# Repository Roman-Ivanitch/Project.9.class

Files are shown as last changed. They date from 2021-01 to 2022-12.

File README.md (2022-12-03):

# Project.9.class 
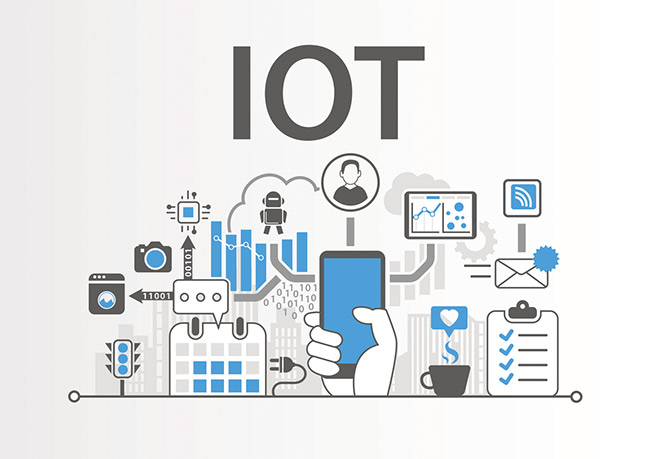
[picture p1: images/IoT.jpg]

___
## Проект 9 класс Рабочая лампа.
## Проект 10 класс Умная лампа V2.
Красикова Романа RassirHakerCorporation@mail.ru 
+ [Страница проекта эектронной начинки в EasyEDA](https://easyeda.com/RassirHaker/10-class)
+ [Сборка лампы](https://github.com/Roman-Ivanitch/Project.9.class/blob/main/dimensional_drawing/README.md)
+ [Настройки в прошивке](https://github.com/Roman-Ivanitch/Project.9.class/tree/main/program_code#readme) 
+ [Руководство по настройке](https://github.com/Roman-Ivanitch/Project.9.class/blob/main/user_manual.md)
+ [Источники информации](https://github.com/Roman-Ivanitch/Project.9.class/blob/main/sources_of_information/README.md)
+ [Исходники кода](https://github.com/Roman-Ivanitch/Project.9.class/blob/main/source_codes/README.md)
## :bulb: Что это такое
Лампа, крепящаяся на стенку над столом. На лампе 2 ряда светодиодной 12-24 вт. Ленты и ряд адресной светодиодной ленты (60 LED/м) отрезками 730 мм. 
Управляется через телефон приложением Blynk (не новым Blynk IoT). Лента уложена в продольные канавки (пазы), 
тем самым не ослепляет и освещает нужную рабочую зону. Изготовлена из "Планкена" 90мм. Питается от внешнего блока питания 12в 3а.

В папке elecktronika находиться гербер файл для заказа плат (я заказывал на [JLCPCB](https://jlcpcb.com/)). 
На плате находиться модуль(микроконтроллер) ESP12f(даташит в папке материалы, источники),
2 mosfet ключа, реле 5V, понижающий регулируемый(калибровочный)) DC-DC преобразователь, стабилизаторы напряжения  3,3 и 12 вольт.

Плату можно питать в диапазоне 10-18 вольт. на плате лишний стабилизатор напряжения на 12 вольт, если его убрать то рекомендую питать от БП 12В, если оставить, то от 14 вольт, но лучше наверно будет поставить вместо стабилизатора стабилитрон. в течении последующего года это страница будет обновляться, скорее всего разведу новую более совершенную универсальную плату. Актуальную плату лучше смотреть на [EasyEDA](https://easyeda.com/RassirHaker/10-class). 

Более подробное описание: 
+ [Проект_9_класс.docx](https://github.com/Roman-Ivanitch/Project.9.class/blob/main/%D0%9F%D1%80%D0%BE%D0%B5%D0%BA%D1%82_9_%D0%BA%D0%BB%D0%B0%D1%81%D1%81.docx) проект на олимпиаду по технологии 9 класс
+ [Проект_10_класс.docx](https://github.com/Roman-Ivanitch/Project.9.class/blob/main/%D0%9F%D1%80%D0%BE%D0%B5%D0%BA%D1%82_10_%D0%BA%D0%BB%D0%B0%D1%81%D1%81.docx) проект на олимпиаду по технологии 10 класс
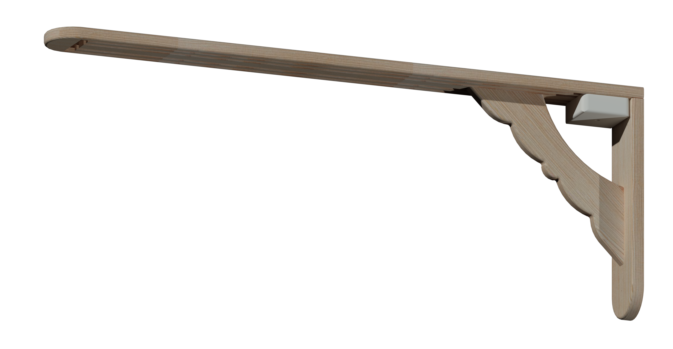
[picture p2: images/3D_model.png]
3d

## QR-code страницы проекта на github 
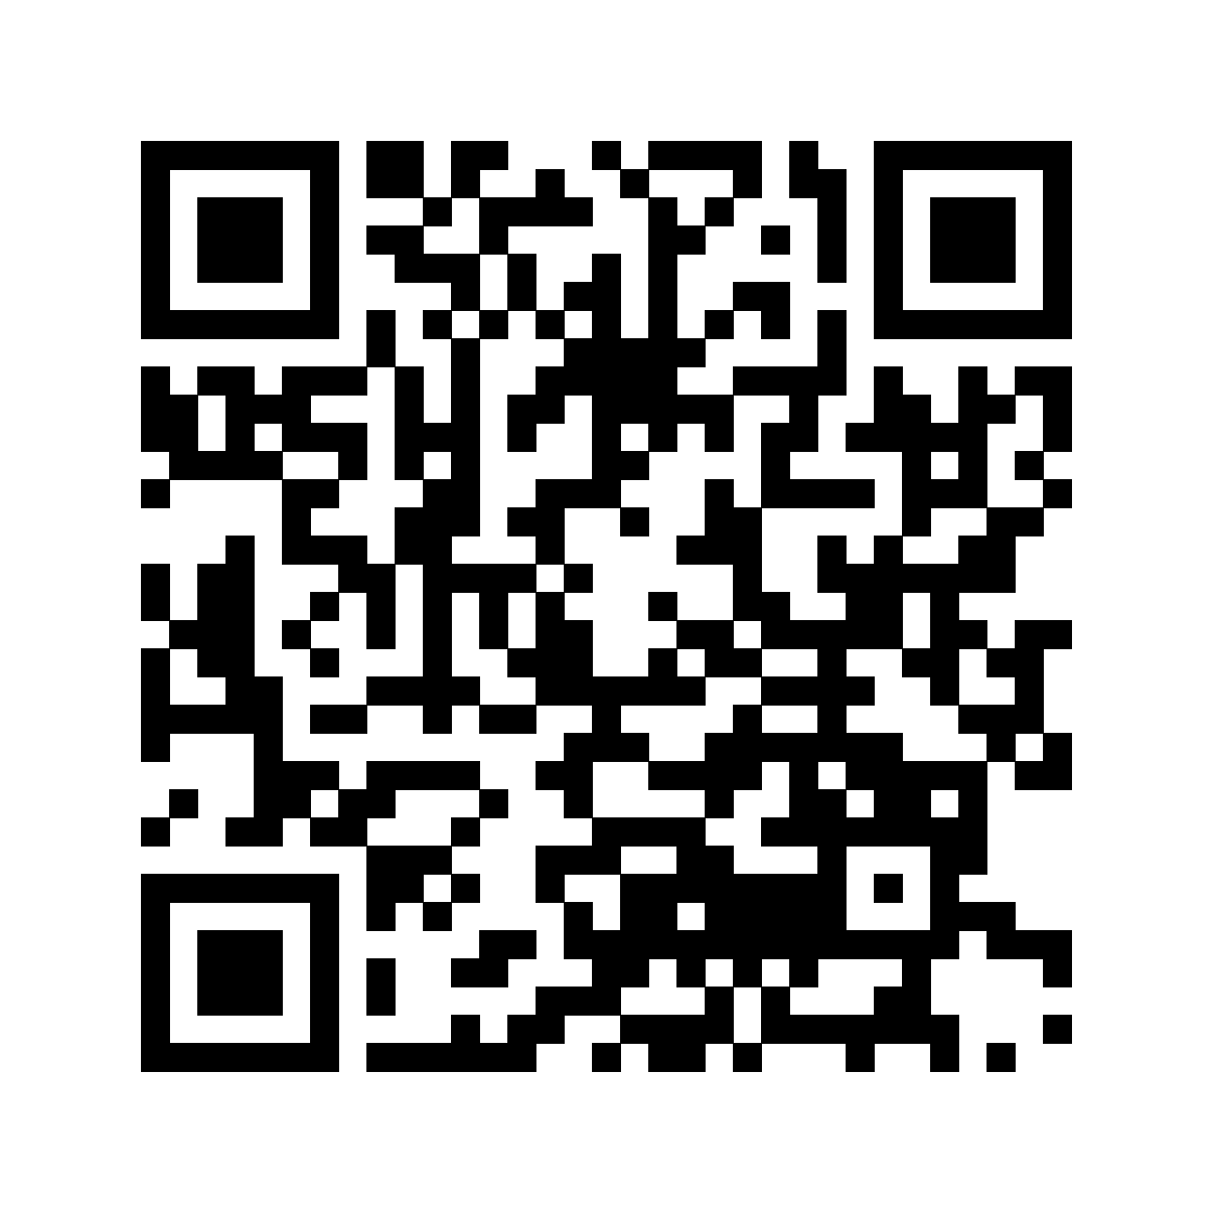
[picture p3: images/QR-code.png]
Qr-code

___

Репозиторий не переименован, потому что на печатных пплатах я указал эту ссылку. Если переименую ссылка по url будет не доступна, а платы уже изготовлены. 

Первый опыт работы в гите...

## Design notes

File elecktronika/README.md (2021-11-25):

# БОЛЕЕ АКТУАЛЬНАЯ ВЕРСИЯ НА [EasyEDA](https://easyeda.com/RassirHaker/10-class)
+ BOM_Smart Lamp V2_2021-09-25.csv - таблица используемых компонентов
+ Gerber_PCB_10 class_1.zip - гербер файл платы электроники
+ Gerber_END_2021-09-25.zip - гербер файл платы соединений ленты (для удобства, внешней информации и красоты)
+ Schematic_10 class_2021-09-17.png - схема, актуальную смотри на [EasyEDA](https://easyeda.com/RassirHaker/10-class)

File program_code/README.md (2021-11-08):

# Program code 
Код писал в Arduino EDA, как настраивать читайте [тут](https://alexgyver.ru/arduino-first/)

Мои ссылки менеджера библиотек:
> https://dl.espressif.com/dl/package_esp32_index.json

> http://arduino.esp8266.com/stable/package_esp8266com_index.json

Код в папке start потому, что первый файл кода назван start, особенность Arduino EDA.

## Settings 
___
Для работы с блинком надо свой токен, но так как у лампы есть тумблер переключения сети, что бы можно задать несколько серверов и wifi сети, то для каждого сервера и wifi сети надо задать свои настройки. 

Если мы используем несколько серверов то для каждого сервера надо указать свой токен
```C++
char auth[] = "токен";          // лампа Blynk-cloud.com // Токен приложения Blynk
char auth_server[] = "токен";   // лампа local-server    // Токен приложения Blynk
```
Так же если используем свой сервер, то надо и задать его ip адрес, в моём случае, для доступа из сети интернет я подключил статический ip адрес (для оф.сервера задавать ip не нужно)
```C++
char ip_local[] = "ip адрес";             // свой server - local ip   // к примеру 192.168.88.200
char ip_net[] = "ip адрес";               // свой server - internet ip
```
Так же в коде надо задать параметры wifi сети, пароль и ssid
```C++
char ssid_home[] = "wi-fi-home-0000575";  // сеть wi-fi
char pass_home[] = "7851xdwifi";          // Пароль WiFi

char ssid_phone[] = "A30";                // Мобильная точка доступа WiFi
char pass_phone[] = "87651234";           // Пароль WiFi

```
Пины подключения ленты/тумблера/обвязки (пины подключены как на печатной плате)
```C++
#define LED_DT  4               // Пин, куда подключен DIN ленты
#define LED     14              // Пин подключения лампы
#define LED1    12              // Пин подключения реле 

#define NET1 5                  // пин подключения кнопки выбора сети 1              
#define NET2 13                 // пин подключения кнопки выбора сети 2
```
Так же надо указать число светодиодов в подключеной адресной ленте
```C++
#define LED_COUNT 50            // Число светодиодов в кольце/ленте
```
### Вот собственно все настройки! 
___
Единственное правда можно поиграть с назначениями положения тумблера
```C++
  // Запуск Blynk (подключение,токен,WiFi,пароль) в зависимости от кнопки // выбор сети

  if (digitalRead(NET1) == 1) Blynk.begin(auth, ssid_phone, pass_phone); 
  // мобил точка доступа и Blynk-cloud.com

  else if (digitalRead(NET2) == 1) Blynk.begin(auth_server, ssid_phone, pass_phone, ip_net, 8080);
  // мобил точка доступа и свой сервер через интернет

  else Blynk.begin(auth_server, ssid_home, pass_home, ip_local, 8080);
  // точка доступа wifi  и свой локальный сервер

```
## tabs 
___
+ start.ino - настройки, функции setup и loop
+ blynk.ino - назначение виртуальных пинов приложения блинк
+ function.ino - функции обработки и воспроизведения режимов, писал не я, брал у [AlexGyver](https://alexgyver.ru/ws2812b-fx/)
+ leds.ino - эффекты для адресной ленты

## libraries
___
+ [FastLED](https://github.com/FastLED/FastLED) 
+ [blynk](https://github.com/blynkkk/blynk-library/releases/tag/v0.5.1), документацию читайте [тут](http://docs.blynk.cc/)

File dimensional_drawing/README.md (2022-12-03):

# Конструкция и сборка лампы
lamp
## Детали
---
Для лампы есть чертежи, 3D модели и эскизы. 
Также есть технологические карты в [проексте](https://github.com/Roman-Ivanitch/Project.9.class/blob/main/%D0%9F%D1%80%D0%BE%D0%B5%D0%BA%D1%82_10_%D0%BA%D0%BB%D0%B0%D1%81%D1%81.docx), не блещут качеством, но всёже есть.

в папках:

+ [basis](https://github.com/Roman-Ivanitch/Project.9.class/tree/main/dimensional_drawing/basis) - основание лампы

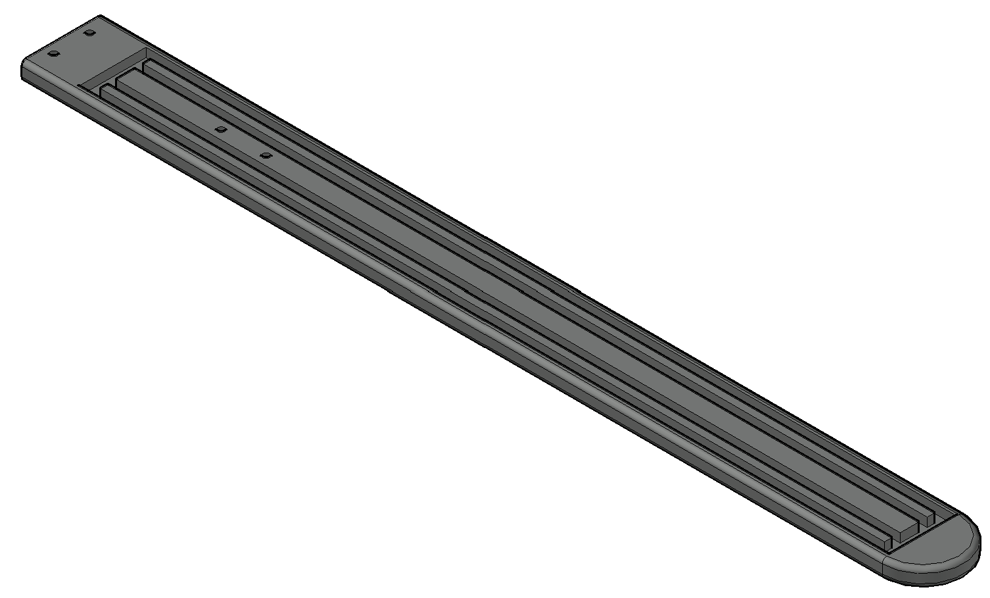
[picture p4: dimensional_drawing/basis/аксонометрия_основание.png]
basis


+ [support](https://github.com/Roman-Ivanitch/Project.9.class/tree/main/dimensional_drawing/support) - опора лампы

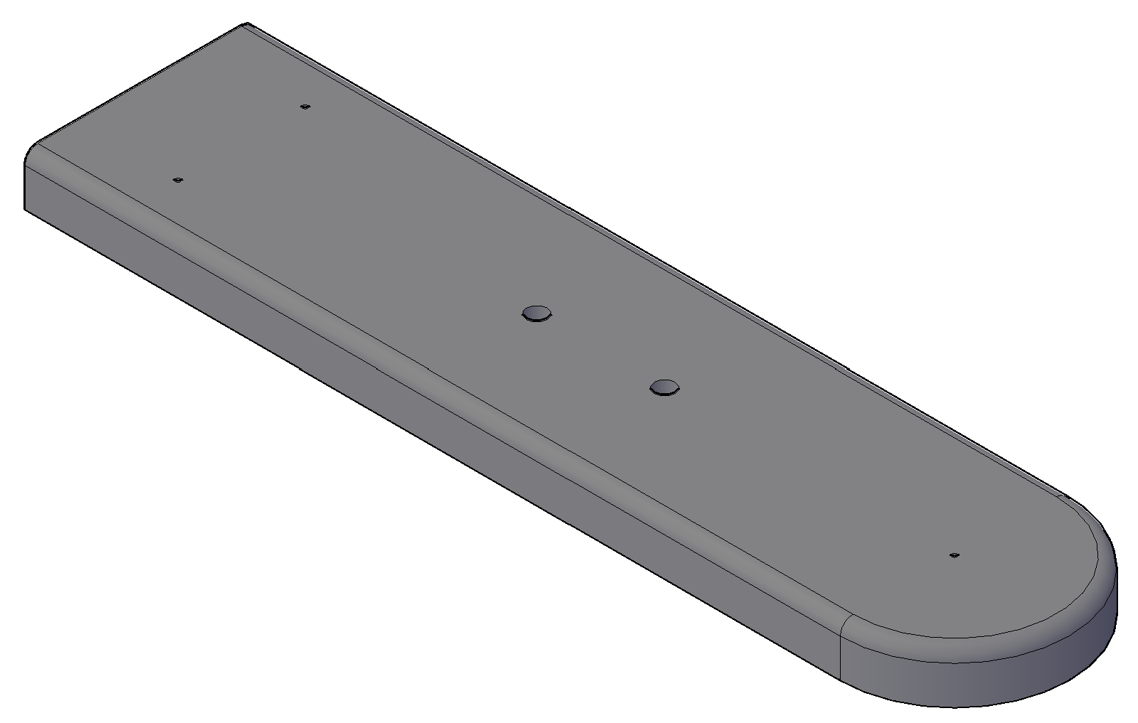
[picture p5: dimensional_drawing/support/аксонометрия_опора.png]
support


+ [gusset](https://github.com/Roman-Ivanitch/Project.9.class/tree/main/dimensional_drawing/gusset) - косынка лампы, с чертежом туго/некачественно, но всёже есть

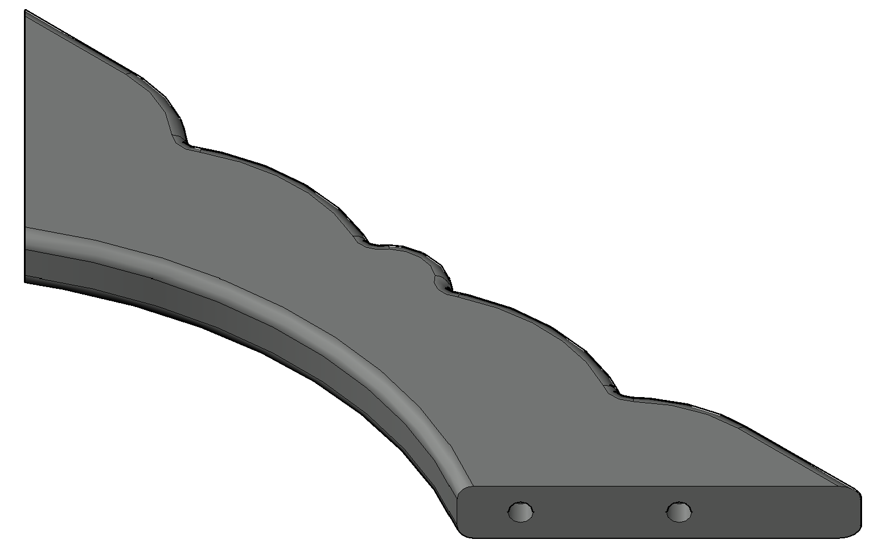
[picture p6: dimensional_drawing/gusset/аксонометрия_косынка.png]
gusset


+ [junction_box](https://github.com/Roman-Ivanitch/Project.9.class/tree/main/dimensional_drawing/junction_box) - 3D модель распред коробки, я использую купленную под цвет лампы, но как появится 3D принтер, распечатаю свою 

+ [lamp](https://github.com/Roman-Ivanitch/Project.9.class/tree/main/dimensional_drawing/lamp) - собранная лампа, со всеми видами

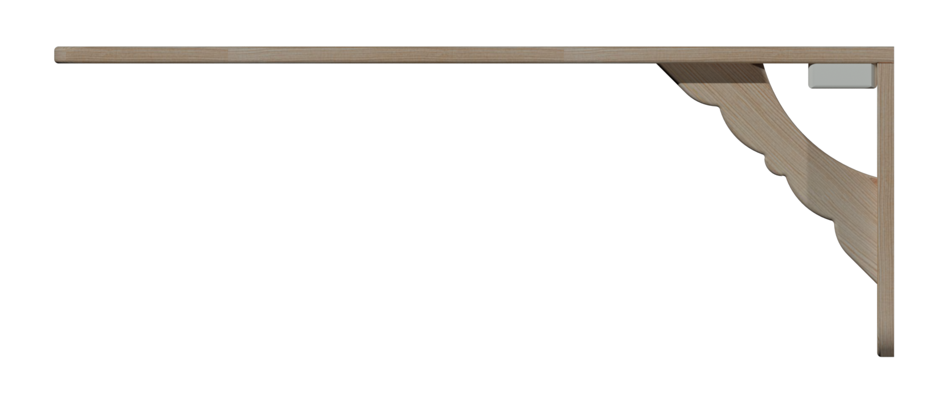
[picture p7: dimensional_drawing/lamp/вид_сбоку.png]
lamp


## Сборка
---

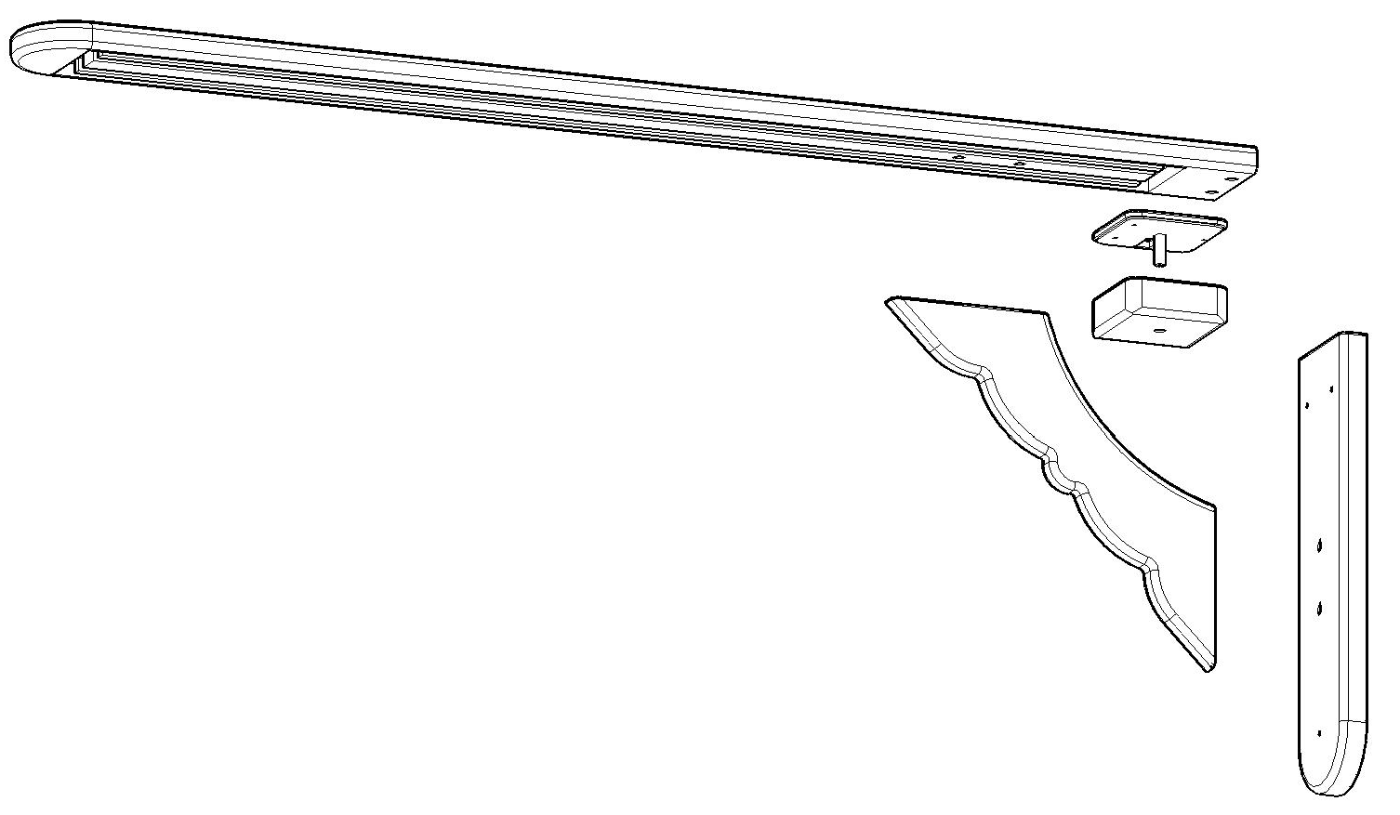
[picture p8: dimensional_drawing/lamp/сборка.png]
Сборка


Сборка лампы осуществляется на круглые вставные штифты 20 х Ø8 мм, распред коробка крепиться ко снованию на два саморезика и крепиться на стену при помощи шурупов 75 мм, которые закрываються мебельными заглушками.

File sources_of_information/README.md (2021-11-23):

# Источники 
## Ссылки 
+ Ютуб канал [AlexGyverShow](https://www.youtube.com/c/AlexGyverShow) много видео в адресной лентой( у него взяты идеи и исходники для первой лампы)
+ Ютуб канал [Инженерка](https://www.youtube.com/c/%D0%98%D0%BD%D0%B6%D0%B5%D0%BD%D0%B5%D1%80%D0%BA%D0%B0), все видео связаны с Blink
+ [Уроки на сайте Alexgyver](http://alexgyver.ru/arduino_lessons/)
+ [Как пользоваться github](https://www.youtube.com/watch?v=JfpCicDUMKc&t=1s) :smile: 
+ [Как развести печатную плату](https://www.youtube.com/watch?v=qXS617cC6Bw&t=0s)
+ [Как развести печатную плату в easyeda](https://youtu.be/9FS1m_K8aWI)
+ [Тоже инфа про платы](https://alexgyver.ru/lessons/naked-chip)
## Литература 
+ [Архетектура интернета вещей](https://github.com/Roman-Ivanitch/Project.9.class/blob/main/sources_of_information/%D0%90%D1%80%D1%85%D0%B8%D1%82%D0%B5%D0%BA%D1%82%D1%83%D1%80%D0%B0%20%D0%B8%D0%BD%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) - Перри Ли
+ [Интернет вещей Иследования и область применения](https://www.chitai-gorod.ru/catalog/book/892185/) - Е.П Зараменских И.Е Артемьев
+ [ARDUINO от азов програмирования до создания практических устройств](https://www.chitai-gorod.ru/catalog/book/1050770/) - Белов А.В
+ [Управление модулем ARDUINO по WiFi с мобильных устройств](https://www.chitai-gorod.ru/catalog/book/1224716/) - Белов А.В
+ [Учебное пособие Интернет вещей](https://github.com/Roman-Ivanitch/Project.9.class/blob/main/sources_of_information/%D1%83%D1%87%D0%B5%D0%B1%D0%BD%D0%B8%D0%BA%20%D0%98%D0%92%20%D0%A0%D0%BE%D1%81%D0%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) - (учебник ИВ Росляков)  А. В. Росляков, С. В. Ваняшин, А. Ю. Гребешков
+ [ESP8266_Pinout]https://github.com/Roman-Ivanitch/Project.9.class/blob/main/sources_of_information/ESP8266_Pinout_Diagrams.pdf) - распиновка модулей ESP8266
+ [Datasheet_ESP12f](https://github.com/Roman-Ivanitch/Project.9.class/blob/main/sources_of_information/ai-thinker_esp-12f.pdf) - даташит модуля ESP12f

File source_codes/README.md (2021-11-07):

# Исходники source_codes 
+ [Bridge Мост Blynk](https://www.youtube.com/watch?v=jMqfWySQdbk) - [download](https://yadi.sk/d/I97H1rZ83KzqM6)
+ [Переподключение Blynk](https://www.youtube.com/watch?v=k9q7FT3p9dM&t=964s) - [download](https://yadi.sk/d/FLdh-S9G3Yur3W)
+ [Голосовой асистент Яндекс Алиса управление Blynk](https://www.youtube.com/watch?v=9rQ1yl00WwE&t=1286s) - [download]( https://yadi.sk/d/YaQMMV3Cu8t1OA)
+ [Адресная лента WS2812_FX-master](https://www.youtube.com/watch?v=_h-Vj8Z6hqs&t=445s) - [download](http://alexgyver.ru/ws2812b-fx/), [download from github](https://github.com/AlexGyver/WS2812_FX)
+ [Модифицированная лампа Гайвера](https://www.youtube.com/watch?v=9o8aKMHTWc4&t=6s) - [download](https://yadi.sk/d/7gbUdzGVLFRcXw)

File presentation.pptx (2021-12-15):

## Умная лампа V2

Муниципальное казённое образовательное учреждение
«Средняя общеобразовательная школа п. Алексеевск»

Выполнил: Учащийся 10 класса
МКОУ СОШ п. Алексеевска
Красиков Роман.

п. Алексеевск, 2021г.

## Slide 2


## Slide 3

Разработка. Электроника.

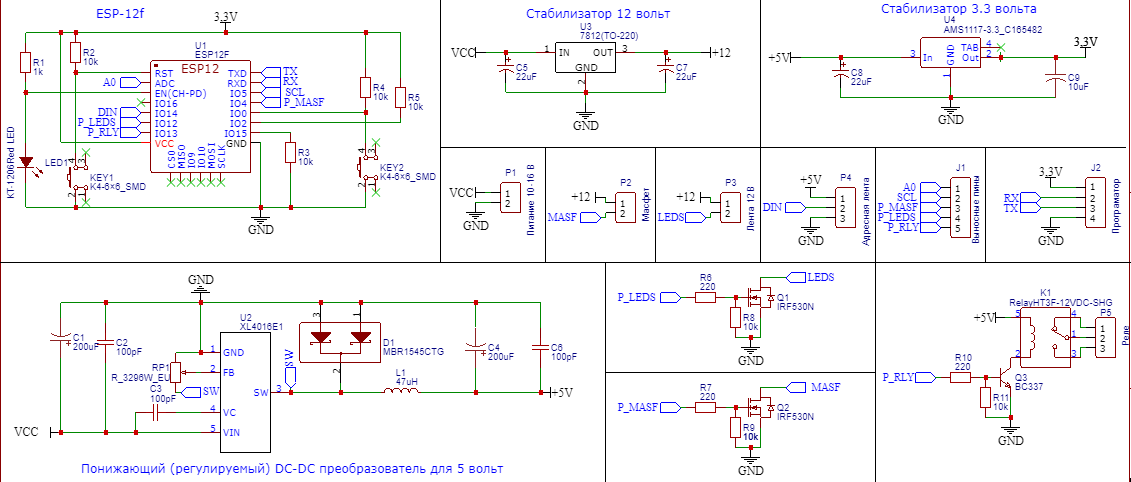
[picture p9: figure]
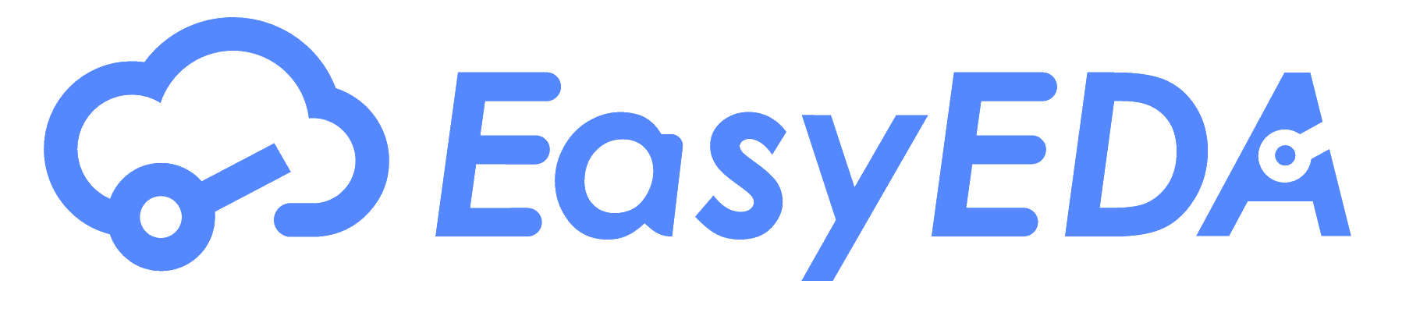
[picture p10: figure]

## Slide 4

Разработка. Дизайн.

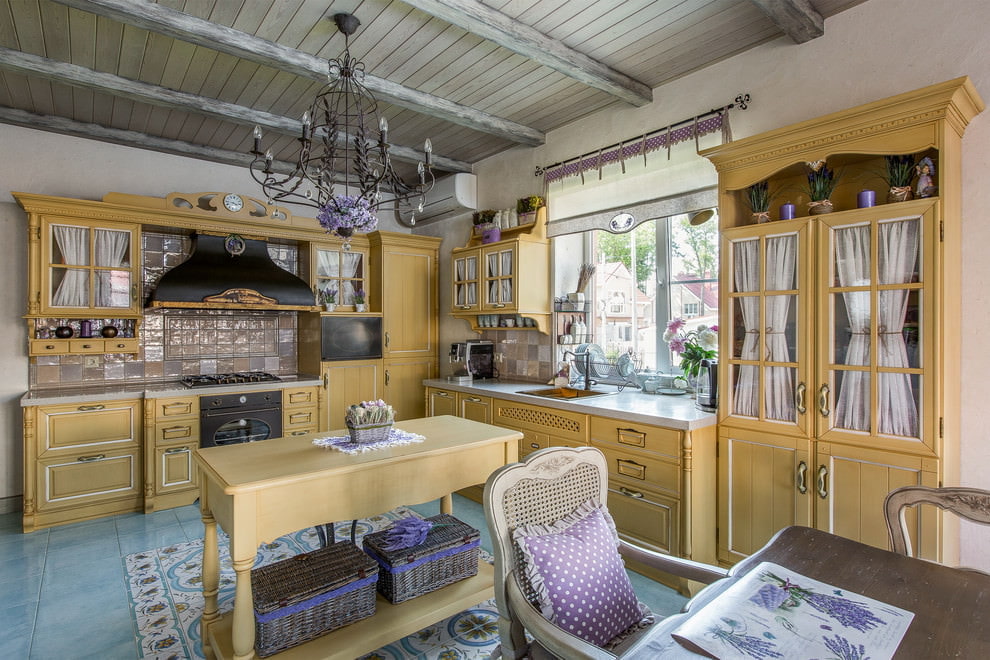
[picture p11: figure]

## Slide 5

Разработка. ПО.

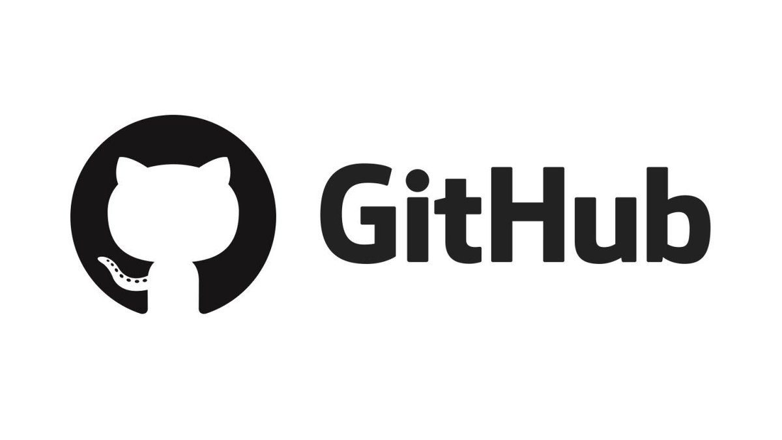
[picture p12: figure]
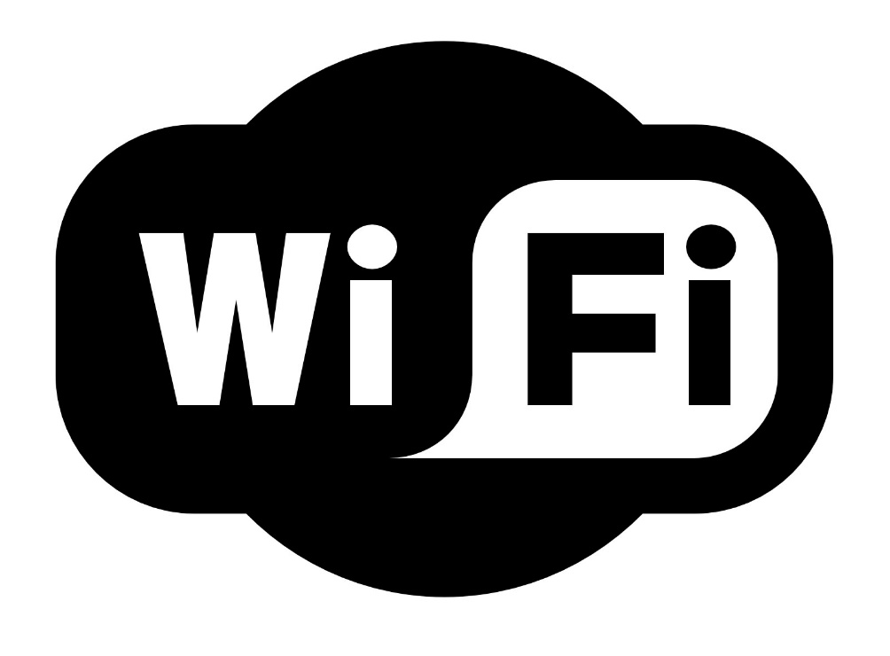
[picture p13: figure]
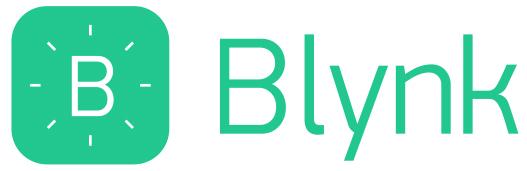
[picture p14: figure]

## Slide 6

Предварительное экономическое обоснование.

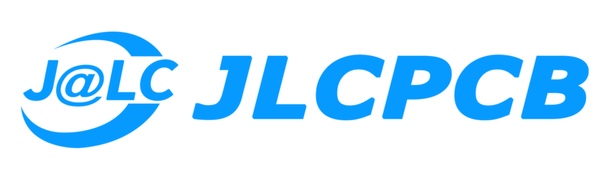
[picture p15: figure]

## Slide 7

Технологический этап. Детали.

опора
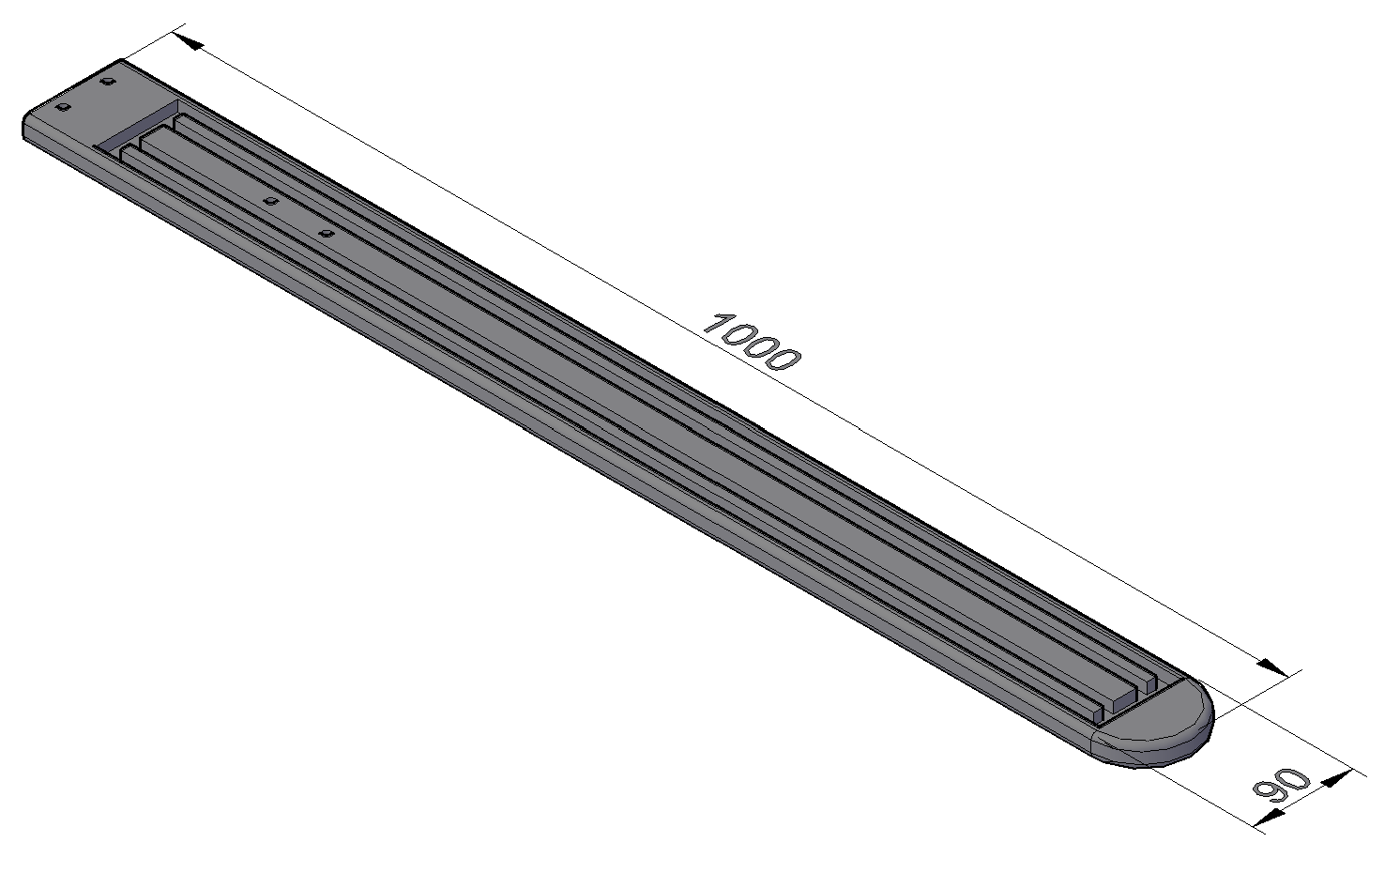
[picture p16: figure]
основание

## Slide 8

Чертежи.

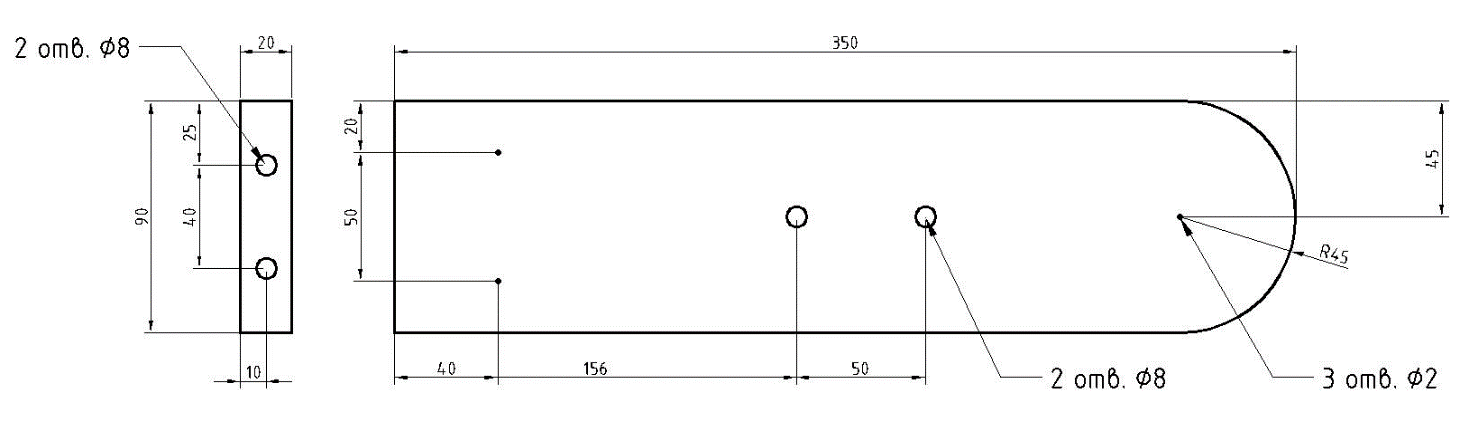
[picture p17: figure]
черчёж_опоры
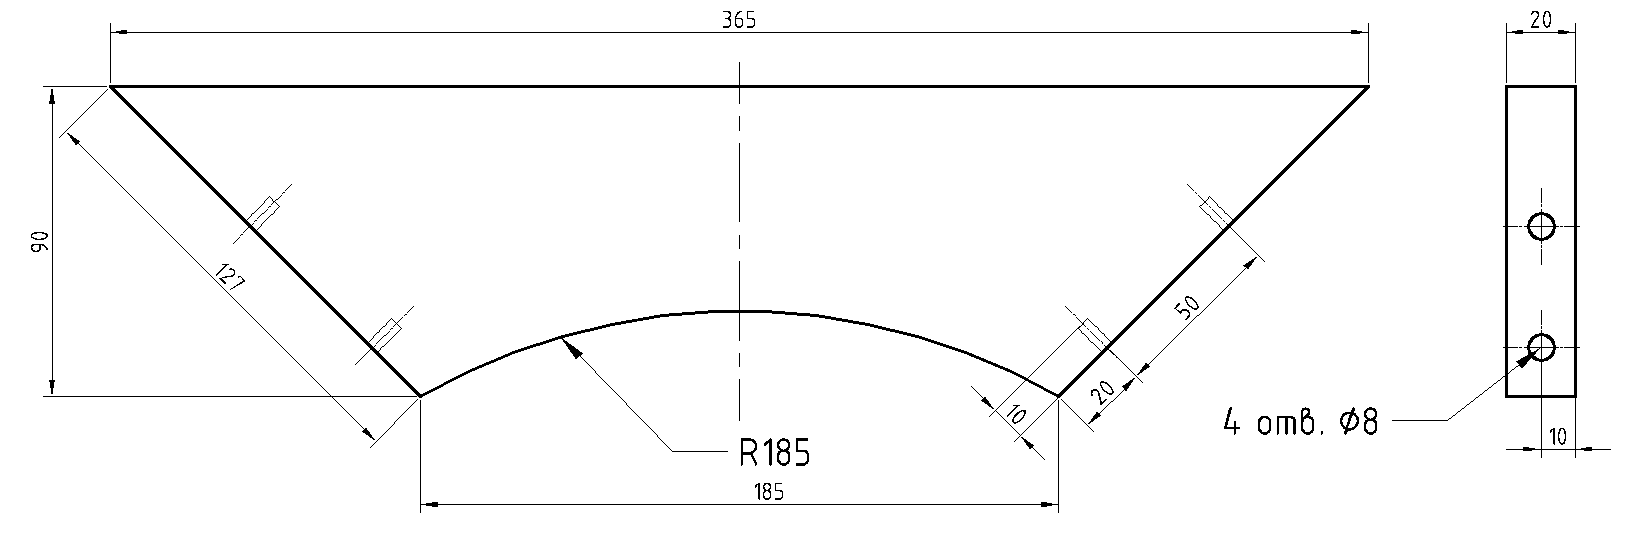
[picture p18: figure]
Черчеж_косынки
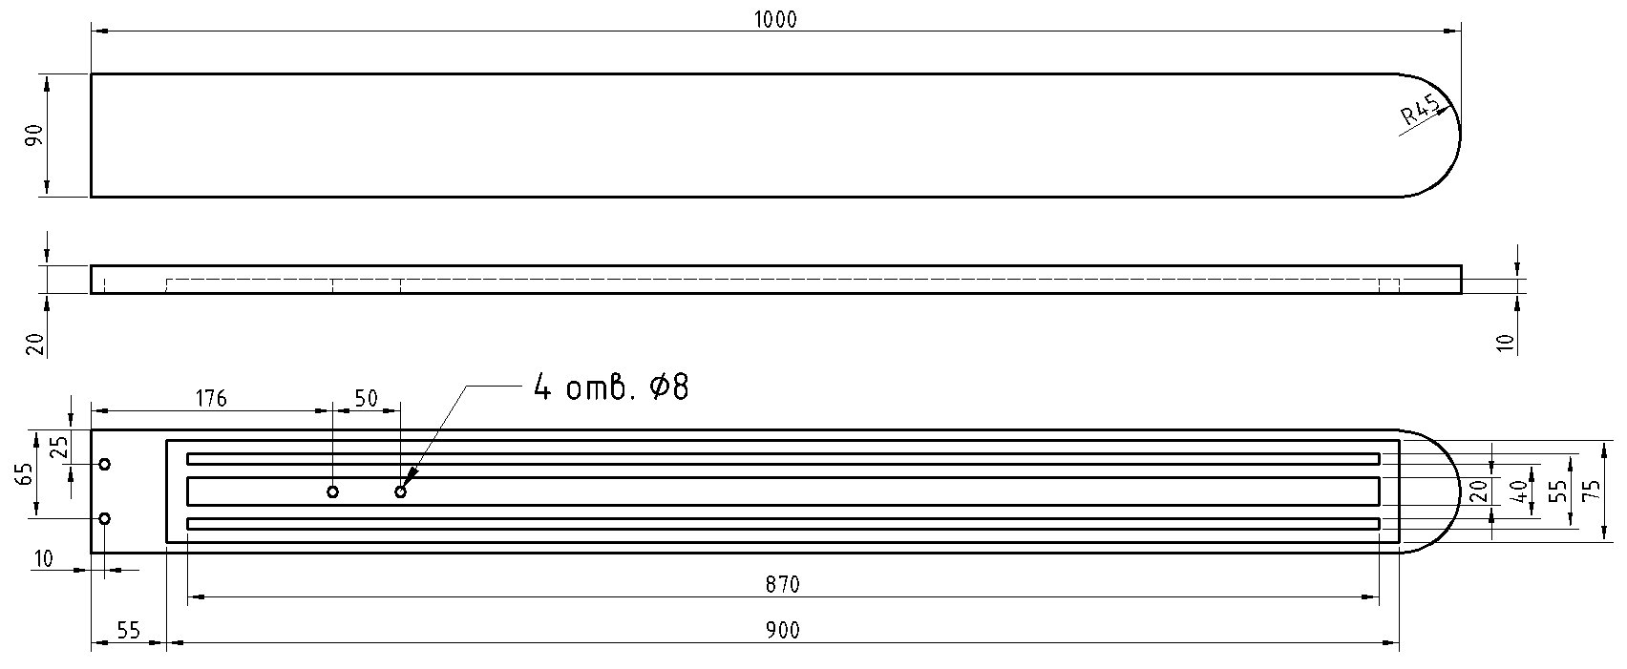
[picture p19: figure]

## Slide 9

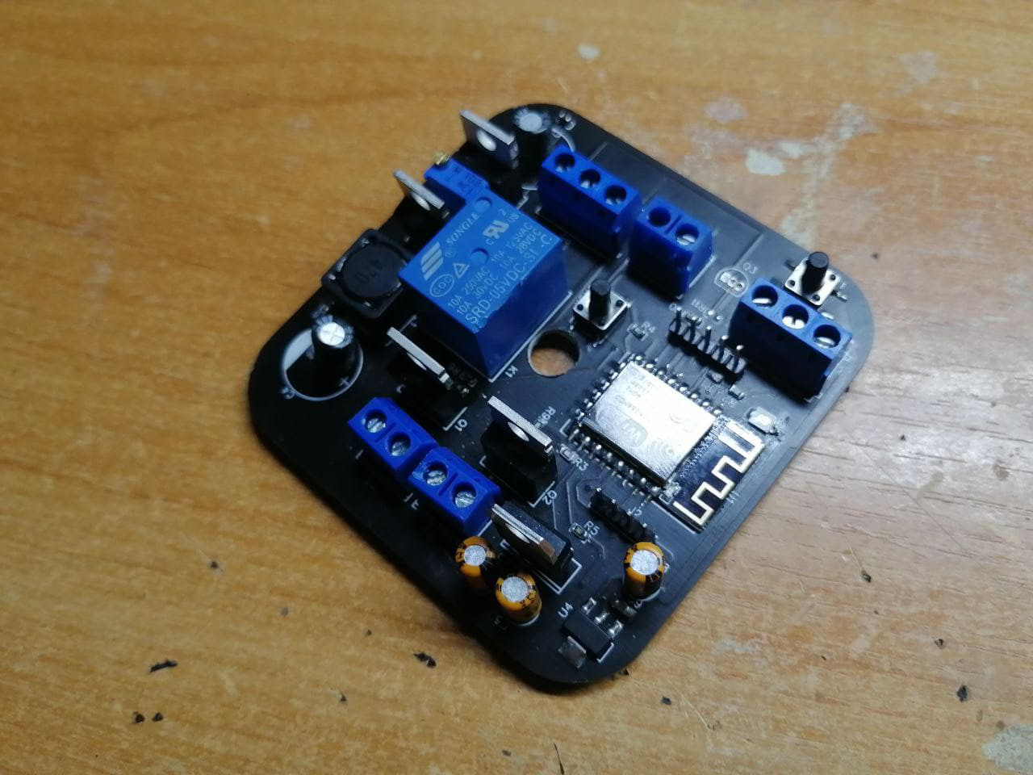
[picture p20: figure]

Печатные платы.

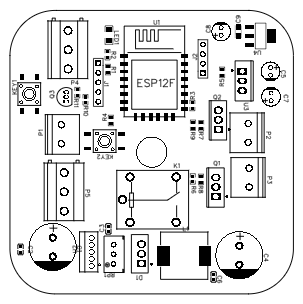
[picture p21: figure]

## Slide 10

красивая_лампа

Сборка изделия.

сборка2

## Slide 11


ПО.

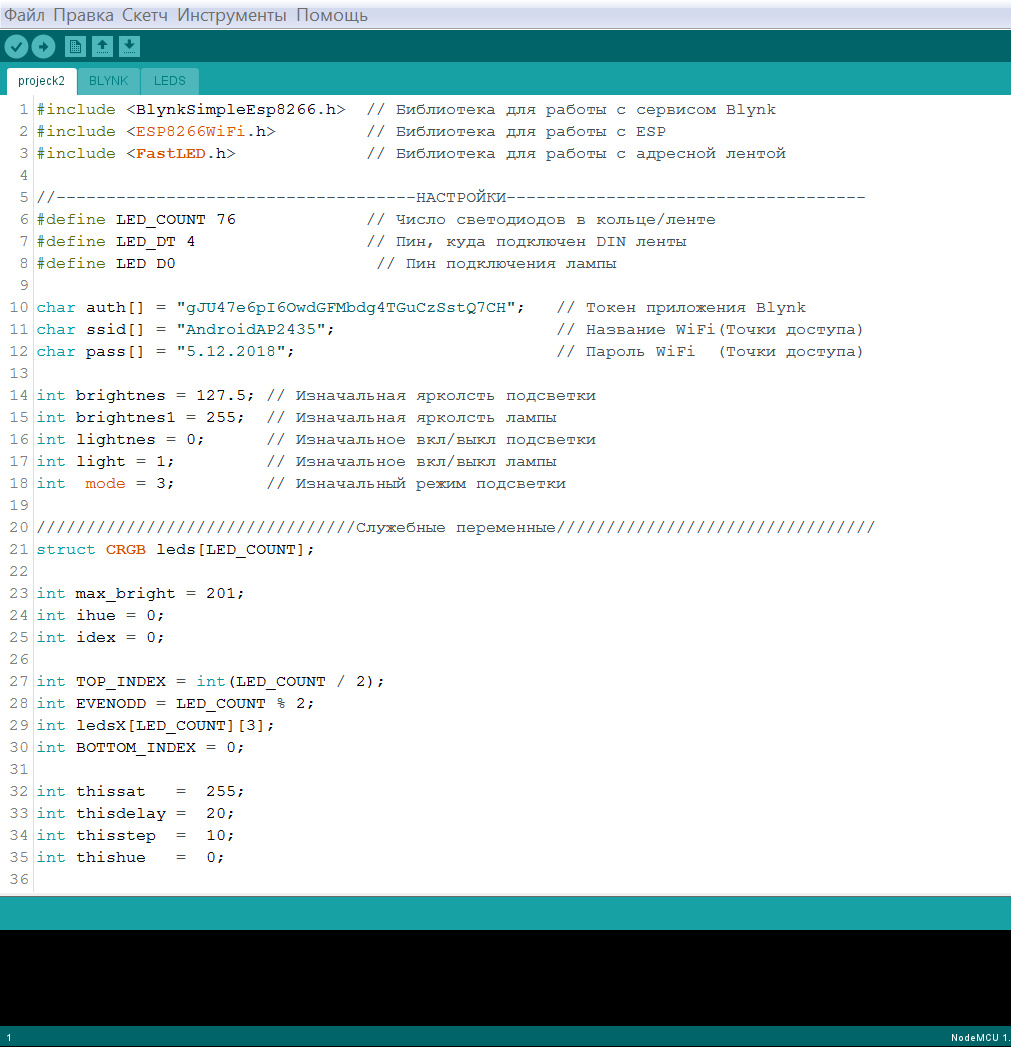
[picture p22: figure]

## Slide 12

Экономическое обоснование.

- Себестоимость моей лампы составила 1264.69 рубля
- Мои затраты составляют 1020 рублей

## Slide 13

Экологическое обоснование.

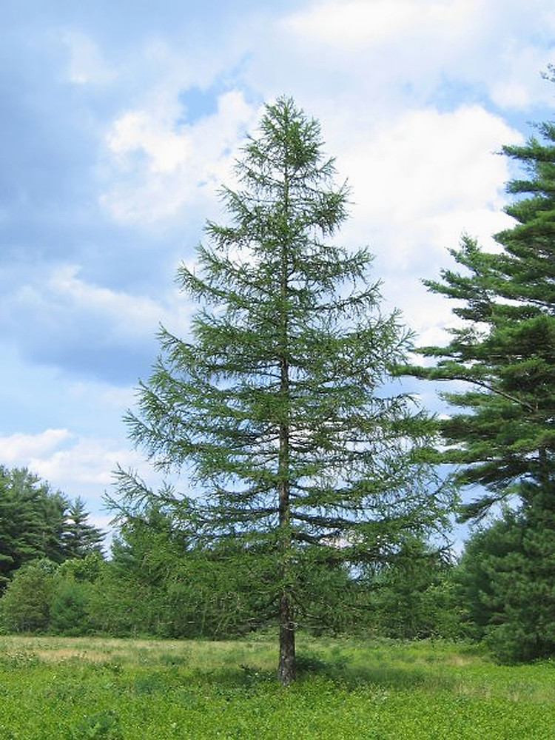
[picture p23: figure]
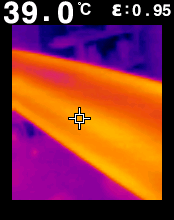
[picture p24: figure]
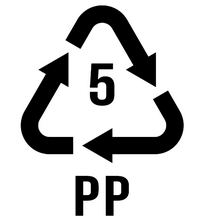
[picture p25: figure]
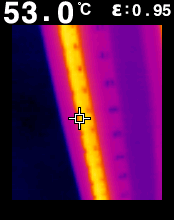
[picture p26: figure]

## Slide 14

Маркетинговое обоснование.

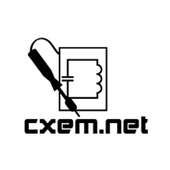
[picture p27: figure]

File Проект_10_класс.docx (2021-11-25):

Муниципальное казённое образовательное учреждение

«Средняя общеобразовательная школа п. Алексеевск»

Умная лампа V2

Выполнил: Красиков Роман

Учащийся 10 класса МКОУ СОШ

п. Алексеевска.

Руководитель: учитель технологии

Кривошеев Сергей Степанович

п. Алексеевск, 2021 г.

# Введение

В повседневной жизни мы часто встречаемся с автоматизированными или «умными» устройствами. Например, у многих смарт часы, измеряющие сердце биение, температуру тела, сожжение калорий, появляется все больше умных чайников, умных розеток и т.д. Всё это концепция IoT. Интернет вещей (Internet of Things - IoT) концепция вычислительной сети физических предметов (вещей) оснащённых встроенными технологиями для взаимодействия друг с другом или с внешней средой. То есть, суть концепции IoT взаимодействие устройств с интернет сетью, с физическим миром и с другими устройствами. Такие устройства будут именно взаимодействовать (Общаться, опрашивать, обрабатывать и исполнять).

Интернет вещей захватит практически каждый сегмент в сфере промышленности, например, в бизнесе - бесконтактная система оплаты услуг, в здравоохранении – устройства которые при ухудшении здоровья вызовут скорую, в потребительских товарах умные часы, автомобили, чайники, лампы и т.д. Влияние интернета вещей проявляется в виде: новых источников дохода, сокращения расходов, повышения производительности. Тем самым тематика интернета вещей очень актуальна и востребована.

В прошлом году я делал рабочую лампу, управляемую по принципу умного дома. В том проекте я создавал очень яркую лампу (24Вт) с разноцветной декоративной подсветкой с разными эффектами. У этого проекта большой потенциал развития. И у меня появилась идея доработать и улучшить, рабочую лампу до «Умной» лампы путём внедрения концепции технологий IoT. Поэтому тему моего проекта я выбираю «Умная» лампа V2.

Цель работы – усовершенствование рабочей до «Умной» лампы

Задачи:

- Изучить концепцию IoT (историю, актуальность, масштабность, нюансы)
- Увеличить функциональность лампы путём добавление новых функций
- Доработать программное обеспеченье для «умности» лампы
- Разработать схему электронной составляющей лампы
- Спроектировать печатную плату электронной составляющей
- Разработать улучённый дизайн рабочей лампы

# 1 Этап проектирования

## 1.1 История и перспективы развития интернета вещей


Понятие Интернета вещей размытое. В разных источниках по поводу возникновения концепции разная и размытая информация. Но знание — это совокупность информации с разных источников, и многие источники сходиться в следующем. Термин «интернет вещей» обязан своим появлением Кевину Эштону, который в 1997 году для управления системой поставок применил технологию радиочастотной идентификации (RFID). С тех пор интернет вещей со вершил переход от простых радиочастотных меток к экосистеме и индустрии, которая к 2020 г. привлечет, создаст или поглотит 5 трлн долларов из 100 трлн мирового ВВП, т. е. 6% мирового ВВП. Вплоть до 2012 г. идея подключения вещей к интернету преимущественно относилась к смартфонам, планшетам, ПК и ноутбукам. По сути, к тем вещам, которые во всех отношениях выступают в качестве компьютера. До этого, с момента появления первых робких зачатков интернета (таких как созданная в 1969 г. сеть ARPANET), большинства технологий, на которых строится интернет вещей, просто не существовало. До 2000 г. большинство устройств, которые можно было подключить к интернету, представляло собой компьютеры различных размеров. Таблица 1 демонстрирует постепенное подключение вещей к интернету.

Рисунок.1 - IoT [1]

Различное понимание обуславливает существование множества различных определений, каждое из которых делает акценты на соответствующих особенностях понятия. Я же решил взять как основное определение Интернета вещей из книги «Архитектура интернета вещей» [2]: Интернет вещей (IoT) (англ. Internet of Things, IoT) – концепция вычислительной сети физических предметов («вещей»), оснащенных встроенными технологиями для взаимодействия друг с другом или с внешней средой. Так как это понятие лучше всего подходит со стороны проектировщика.

Интерес мировой общественности к интернету вещей

Заявки на патенты, публикации в журнале IEEE, доклады на конференциях, данные аналитики Google Trends

Данные аналитики поисковых запросов Google TrendsКоличество коллегиально отредактированных статей

и публикаций

Всемирные заявки на патент

Количество коллегиально отредактированных и опубликованных статей и публикаций

Данные аналитики поисковых запросов Google

Всемирные заявки на патент

Рисунок.2 - Интерес мировой общественности к интернету вещей [2]

На рисунке 2 показан анализ ключевых слов при поиске информации об интернете вещей, патентах и технических публикациях.

Интернет вещей захватит практически каждый сегмент в сфере промышленности, бизнеса, здравоохранения и потребительских товаров.

На основе Интернета вещей могут быть реализованы всевозможные «умные» (smart) приложения в различных сферах деятельности и жизни человека (рис. 1.20):

«Умная планета» – человек сможет буквально «держать руку на пульсе» планеты: своевременно реагировать на упущения в планировании хозяйств, загрязнения и другие экологические проблемы, а значит, эффективно распоряжаться не возобновляемыми ресурсами.

«Умный город» – городская инфраструктура и сопутствующие муниципальные услуги, такие как образование, здравоохранение, общественная безопасность, ЖКХ, станут более связанными и эффективными.

«Умный дом» – система будет распознавать конкретные ситуации, происходящие в доме, и реагировать на них соответствующим образом, что обеспечит жильцам безопасность, комфорт и ресурсосбережение.

«Умная энергетика» – будет обеспечена надежная и качественная передача электрической энергии от источника к приемнику в нужное время и в необходимом количестве.

«Умный транспорт» – перемещение пассажиров из одной точки пространства в другую станет удобнее, быстрее и безопаснее.

«Умная медицина» – врачи и пациенты смогут получить удаленный доступ к дорогостоящему медицинскому оборудованию или к электронной истории болезни в любом месте, будет реализована система удаленного мониторинга здоровья, автоматизирована выдача лекарственных препаратов больным и многое другое.

Влияние интернета вещей или любой другой технологии проявляется в виде:

  - новых источников дохода (получение электроэнергии экологически чистым методом);
  - сокращения расходов (уход за пациентами на дому);
  - сокращения срока вывода продукта на рынок (автоматизация производства);
  - усовершенствования структуры цепочки поставок (учет материальных активов);
  - сокращения производственных потерь (кража, порча товаров с коротким сроком годности);
  - повышения производительности (машинное обучение и анализ данных).

## 1.2 Разработка умной лампы

Функциональность умной лампы

Для новой версии моей лампы надо определиться с новым функционалом и требованиями моей лампы, поскольку мой проект является доработкой и улучшением прошлогодней лампы и в этом проекте я нацелен на получение новых знаний с добавление новых функций.

Во-первых, новая версия лампы должна быть выполнена намного качественней. Путём реализации новых знаний, новых программ для проектирования, и заказа печатных плат промышленного качества у компании JLCPCB.

Во-вторых, должен быть улучшенный дизайн лампы, для улучшения эстетичности. Лампа должна приобрести более сложные криволинейные линии.

В-третьих, добавление новых функций и решений. Путем улучшения и доработки ПО и электронной составляющей.

Разработка электронной составляющей

Для управления лампы нужна электронная начинка, которая и будет управлять не посредственно освещением. Для электронной составляющей для начала надо разработать принципиальную схему. В прошлом проекте, который взят за основу, электронная начинка была сделана из модулей с радиодеталями на макетной плате. Тем самым от прошлого проекта принципиальная схема не подойдет, к тому же она не идеальна из-за отдельных модулей. (которые создают дополнительные шумы) Мною была разработана не посредственно новая принципиальная эл. схема в которую входит Dc-Dc преобразователь, микроконтроллер ESP-12f, транзисторные ключи, реле, стабилизаторы напряжения.

Сборка электронной схемы может быть произведена тремя способами: пайка навесом, пайка на макетной плате и сборка на печатной плате. Пайка навесом хороша своей простотой и доступностью, но очень трудно делать более трудные схемы и не имеет механической прочности. Макетная плата удобна при создании простых схем или прототипов. Печатная плата трудна в производстве в домашних условиях.

Для большей точности и стремления к высокому качеству изготовления, я решил изготовить электронную составляющую на печатной плате, ведь в 21 веке можно заказать в Китае изготовление печатных плат на заводе станочным оборудованием по низкой цене с высочайшим качеством. Для этого надо разработать принципиальную схему и спроектировать не посредственно саму печатную плату. Разрабатывал и проектировал я в среде разработки EasyEDA. Среда разработки доступна в бесплатном доступе, как для скачивания, так и WEB-версия.

Плата будет представлять собой техническое устройство у которого будут контакты подключения светодиодных лент; контакты реле; выносные контакты микроконтроллера для возможности подключения дополнительных модулей/сенсоров/датчиков; контакты для подключения программатора. На самой плате будет расположен DC-DC преобразователь для понижения напряжения, стабилизаторы напряжения, непосредственно сам микроконтроллер, транзисторные ключи, реле, кнопка перезагрузки и программирования.

Разработка улучшенного дизайна


Поскольку мой проект — это улучшение рабочей лампы, сделанной в прошлом году до «умной лампы V2», то естественно прототипом моей умной лампы будет прошлогодняя рабочая лампа. В прошлом году я уже рассматривал прототипы для свое лампы и разработал конструкцию. В этом году мне хочется надо внести больше декора для эстетичности. В свою лампу хотелось бы внести криволинейных линий, фрезерованных краёв, более декоративных форм. Меня очень впечатляет стиль «Прованс» (рисунок 3) где свойственно: наполнение элементами с эффектом состаренности, предпочтительно использование натуральных материалов, и цветовая палитра светлая.

Рисунок.3 - Пример стиля «Прованс» [3]

Доработка улучшенного ПО

Для улучшения рабочей лампы до умной, требуется доработать и улучшить программное обеспечения (ПО) ведь мир не стоит на месте, для устройства надо выпускать обновления. Надо улучшать безопасность, оптимизировать и корректировать программный код, а также добавлять новаторские функции, например, такие как управление голосом. В моё ПО внесётся множество доработок и новых функций:

- Исправление ошибок подключения к WiFi
- Исправление ошибки управления яркостью
- Оптимизация программного кода
- Добавления функции взаимодействия и обработка с устройствами подобного типа для дальнейшего их прорабатывания
- Добавления функции взаимодействия с внешними серверами (подключение к домашнему серверу)
- Добавления функции выбора сети (сервера и wifi-сети)
- Добавление поддержки SSL протокола безопасности
- Добавление голосовое управление Яндекс Алиса

Добавление голосового помощника Алиса, даёт возможность включать лампу по расписанию и управлять ей по таймеру. Например, «Алиса, убавь яркость на 20% через час и выключи через 2». Так же, благодаря сервису Умный дом с Яндекс, станет доступно управление лампой через любой устройство с которого выполнен вход в мой аккаунт Яндекса.

Моё ПО можно скачать по ссылке: https://github.com/Roman-Ivanitch/Project.9.class, это страница проекта на GitHub которая последующие несколько лет будет обновляться. На страничке проекта находиться краткое описание проекта, все схемы, источники, исходники, фотографии, ПО, 3D модель, гербер файл для заказа платы на промышленном производстве.

## 1.3 Предварительное эконом обоснование

Моё изделие это новая доработанное и улучшенная версия моего прошлогоднего проекта Рабочая лампа. В новой версии улучшения сделаны с упором на ПО и электронную начинку, поэтому предполагаю, что затраты будут не существенные, потому что написание обновления для микроконтроллера будет стоить только моим временем, а для электронной начинки, будут заказаны платы со скидкой и компоненты будут взяты с прошлой версии. Детали конструкции моей лампы будут тоже взяты с первой версии лампы, остаётся только предать им формы и обработать фрезером.

Затраты составят на печатные платы и эл. Энергию. На сайте jlcpcb где я буду заказывать печатные платы, говориться, что печатные платы размерами до 100х100 мм любой сложности будут стоить 2$.

Могу предположить, что улучшение моей лампы обойдётся мне не больше 500 рублей, включая доставку, стоимость печатных плат и эл. Энергии.

# 2 Технологический этап

## 2.1 Описание изготовления лампы

- Изготовление основы
1. Выбрать заготовку 20×100×1010мм
2. Разметить пазы под LED ленту 5×10×900мм
3. Фрезеровать пазы под LED ленту
4. Снять фаски с пазов
5. Разметить центра отверстия под круглый шип
6. Просверлить отверстия Ø 8 мм
7. Разметить закругление R 45 мм
8. Выпилить лобзиком
9. Обработать кромки фрезером
10. Зачистить заготовку
- Изготовление опоры
1. Выбрать заготовку20×100×350мм
2. Разметить закругление R 45 мм
3. Выпилить закругление
4. Обработать кромки фрезером
5. Зачистить планки
6. Разметить центра отверстия
7. Просверлить отверстия Ø8 мм
8. Зачистить заготовку
- Изготовление косынки
1. Выбрать заготовку 20×100×380мм
2. Разметить углы 45° с обеих сторон
3. Отпилить заготовки под углом 45°
4. Разметить заготовку по шаблону
5. Выпилить лобзиком
6. Обработать кромки фрезером
7. Зачистить планки
8. Разметить центра отверстия
9. Прослерлить отверстия Ø 8 мм
9. Зачистить заготовку
- Изготовление управляющей электроники
1. Подобрать распредкоробку для печатной платы
2. Разметить отверстия под вывод проводов в распредкоробке
3. Просверлить отверстия под вывод проводов
4. Вырезать отверстие для кнопки
5. Установить кнопку и разьём питания
6. Спаять электронику по схеме 1
7. Зачистить места спайки
8. Заизолировать оголённые контакты
- Монтаж ленты и управляющей электроники
1. Проложить LED ленту и провод в паз
2. Установить распределительную коробку с платой на основание
3. Загрузить программное обеспечение на микроконтроллер
- Сборка и установка лампы на стену
1. Соеденить основание, косынку и опору на круглый вставной шип
2. Прикрутить лампу к стене шурупами (60мм) 3 шт
3. Закрыть саморезы мебельнойзаглушкой
4. Подключить питание через блок питания 12 вольт

## 2.2 Детали лампы

### 2.2.1 Основание лампы


Рисунок 3 – Аксономитрическая проекция основания лампы


Черчёж 1 – чертёж основания лампы

Технологическая карта основания лампы – Таблица № 1

| | | Заготовка: доска 20х100х1010
| | | Материал: лиственница
№ | Последовательность операций | Эскиз | | Инструменты и оборудование


1 | Выбор и выпиливание заготовки | | | Линейка, карандаш, ножовка
2 | Разметка заготовки по чертежу | | | Линейка, карандаш, циркуль

эских,выпил

3 | Выпиливание по размерам чертежа | | | Эл. лобзик
4 | Разметка центров отверстий | | | Линейка, шило, кернер, молоток
6 | Сверление отверстий Ø5мм | | | Свёрла, сверлильный станок
7 | Фрезерование заготовки по чертежу | | | Фрезерный станок
8 | Зачистка детали | | | Наждачная бумага

### 2.2.2 Опора лампы


Рисунок 4 – Аксонометрическая проекция опоры лампы


Чертёж 2 – чертёж опоры лампы

Технологическая карта опоры лампы – Таблица № 2

черчёж_опоры

| | | Заготовка: доска 20х100х360
| | | Материал: лиственница
№ | Последовательность операций | Эскиз | | Инструменты и оборудование
1 | Выбор и выпиливание заготовки | | | Линейка, карандаш, ножовка
2 | Разметка заготовки по чертежу | | | Линейка, карандаш, циркуль
3 | Выпиливание по размерам чертежа | | | Эл. лобзик, ножовка
4 | Разметка центров отверстий | | | Линейка, шило, кернер, молоток
5 | Сверление отверстий Ø5мм | | | Свёрла, сверлильный станок

фрезер

6 | Фрезерование кромок заготовки | | | Фрезерный станок
7 | Зачистка детали | | | Наждачная бумага

### 2.2.3 Косынка лампы


Рисунок 5 – Аксонометрическая проекция косынкы лампы


Чертёж 3 – чертёж косынки лампы

Технологическая карта косынки лампы – Таблица № 3

| | | Заготовка: доска 20х100х380
| | | Материал: лиственница
№ | Последовательность операций | Эскиз | | Инструменты и оборудование
1 | Выбор и выпиливание заготовки | | | Линейка, карандаш, ножовка
2 | Разметка заготовки по чертежу | | | Линейка, карандаш, циркуль
3 | Выпиливание по размерам чертежа | | | Эл. лобзик, ножовка

эскиз_разметка_отв

4 | Разметка центров отверстий | | | Линейка, шило, кернер, молоток
5 | Сверление отверстий Ø5мм | | | Свёрла, сверлильный станок
6 | Фрезерование кромок заготовки | | | Фрезерный станок
7 | Зачистка детали | | | Наждачная бумага

## 2.3 Электронная начинка

Схема.1 – Принципиальная схема электронной начинки


Схема.2 – Схема расположения компонентов


Рисунок 7 – печатные платы

Принципиальная схема была составлена мною в бесплатном веб-редакторе EasyEDA [5], схему можно скачать и открыть в моём аккаунте редактора по ссылке: https://easyeda.com/RassirHaker/10-class, а также она есть на странице проекта моего аккаунта Github[5] по ссылке: https://github.com/Roman-Ivanitch/Project.9.class (ссылку можно открыть, отсканировав QR-code 1). В этих же источниках располагаются схемы печатных плат и гребер-файлы для заказа их на предприятии jlcpcb[5].


Рисунок 6 – Собранное устройство

Сборочная карта электронной начинки – Таблица № 4


№ | Последовательность операций | Эскиз | Инструменты и оборудование
1 | Подборка компонентов
2 | Разметка центров отверстий для кнопки и гнезда питания | | Линейка, шило
3 | Сверление и вырезание отверстий, вставить кнопу с гнездом | | Сверло, шуруповерт, напильник
4 | Спайка управляющей эл. цепи | | Паяльник, припой, канифоль
5 | Зачистка мест пайки | | Щётка, спирт
6 | Подключение проводов в винтовые клемы | | отвертка

## 2.4 Сборка лампы


Рисунок 6 – сборочное изображение лампы

Сборка лампы осуществляется на круглые вставные штифты 20 х Ø8 мм и крепиться на стену при помощи шурупов 75 мм.


Рисунок 7 – Общий вид лампы

## 2.5 Программный код для микроконтроллера


Скриншот.1 – Часть программного кода


Для управляющего микроконтроллера я написал программное обеспечение. На скрин.1 изображена часть его, так как весь код, занимает более тысячи строк. Репозиторий можно скачать по ссылке: https://github.com/Roman-Ivanitch/Project.9.class (ссылку можно открыть, отсканировав QR-code 1). Так же там располагается инструкция по настройке кода и приложения.

QR-code.1

# 3 Заключительный этап

## 3.1 Экономическое обоснование

### 3.1.1 Расчёт затрат на материалы и эл. Энергию

Обозначения:

Vкос – Объём косынки Vосн – Объём основания Vопр – Объём опоры Vобщ – Объём изделия Pсвр – мощность потребления сверлильного станка Pфуг – мощность потребления фуговального станка Pфрез – мощность потребления фрезера Pпаял - мощность потребления паяльника Pлоб - мощность потребления эл. лобзика Pосв – мощность потребления освещения Pобщ – общая мощность потребления Цдр – стоимость древесины Цэл – стоимость эл. энергии Цled – стоимость светодиодной ленты Цrgb – стоимость адресной ленты | V – объём [м³] a – длина [м] b – ширина [м] h – высота [м] l – длина [м] P – Мощность эл. прибора [кВт] t – время работы [ч] n – количество [шт] Ц – стоимость ед. измерения [руб]

Эл. Потребление приборов – Таблица № 5

Название эл. прибора | P | t
Pсвр | 0.5 | 0.5
Pфрез | 1 | 0.5
Pфуг | 1 | 0.5
Pосв | 0.015 | 8
Pпаял | 0.065 | 0.5
Pлоб | 0.5 | 0.25

Расчёт материалов – Таблица № 6

обозначение | формула | расчёт | значение | величина
Vосн | a*b*h | 1.01*0.1*0.02 | 0.00202 | М³
Vкос | a*b*h | 0.37*0.1*0.02 | 0.00074 | М³
Vопр | a*b*h | 0.36*0.1*0.02 | 0.00072 | М³
Vобщ | Vкос + Vосн + Vопр | 0.00202+0.00074+0.00072 | 0.00348 | М³
Цдр | Vобщ*Ц | 0.00348*4000 | 13.92 | Руб.
Цled | l*Ц | 1.64*311 | 510,04 | Руб.
Цrgb | l*Ц | 0,84 *434 | 364.56 | Руб.

Расчёт эл. энергии – Таблица № 7

обозначение | формула | расчёт | значение | величина
Pсвр | P*t | 0.5*0.5 | 0.25 | кВт/ч
Pфрез | P*t | 1*0.5 | 0.5 | кВт/ч
Pфуг | P*t | 1*0.5 | 0.5 | кВт/ч
Pпаял | P*t | 0.065*0.5 | 0.0325 | кВт/ч
Pлоб | P*t | 0.5*0.25 | 0.125 | кВт/ч
Pосв | P*n*t | 0.015*48*8 | 5.76 | кВт/ч
Pобщ | Pсвр+ Pкрг+ Pфуг+ Pосв+ Pпаял+ Pлоб | 0.25+0.5+0.5+ 5.76+0.0325+0.125 | 7.1675 | кВт/ч
Цэл | Pобщ*Ц | 7.1675*1,23 | 8.82 | Руб.

Общие затраты – Таблица № 8

№ | Материалы. | Единица измерения. | Стоимость единицы измерения. (Руб.) | Кол–во затраченного материала. | Стоимость материала. (Руб.)
1 | Древесина | М3 | 4000 | 0.00348 | -(13.92)
2 | Светодиодная лента SMD3014 12v 24w 240 led | м. | 311 | 1.64 м | -(510,04)
3 | Адресная лента 2812bip33 14.4w | м. | 434 | 0,84 м | -(364,56)
4 | Микроконтролер ESP12f | Шт. | 72 | 1шт. | - (72)
5 | Резистор 220Ом, 1кОм, 10кОм | Шт. | 0,133 | 7шт. | 0.931
6 | Светодиод KT-1206Red LED | Шт. | 0,41 | 1шт. | 0.41
7 | Транзистор IRF530N | Шт. | 16,842 | 1шт. | -(16,8)
8 | Схема XL4016E1 | Шт. | 41,21 | 1шт. | 41.21
9 | Диод шотки MBR1545CTG | Шт. | 11.124 | 1шт. | 11.124
10 | Стабилизатор напряжения AMS1117-3.3 | Шт. | 7 | 1шт. | 7
11 | Катушка индуктивности | Шт. | 5.2 | 1шт. | 5.2
12 | Потенциометр 10кОм | Шт. | 8.8 | 1шт. | 8.8
13 | Кнопка K4-6×6_SMD | Шт. | 3 | 2шт. | 6
14 | Кнопка | Шт. | 26.89 | 1шт. | - (26.89)
15 | Электролетический Конденсатор 100uF, 22uF | Шт. | 1 | 5шт. | 5
16 | Керамический конденсатор 100pF, 10uF | Шт. | 0.5 | 4 шт. | 2
17 | Винтовые клемы | Шт. | 10.5 | 3 шт. | 31.5
18 | Разьём питания 5.5*2.5 | Шт. | 8,196 | 1шт. | - (8,2)
19 | Провод ШВВП 3*0.75 | м. | 25 | 1м. | - (25)
20 | Распредкоробка | Шт. | 40 | 1шт. | - (40)
21 | Печатные платы | Шт. | 29.74(0.4$) | 2шт. | 446.1(59.48)
22 | Эл. энергия | кВт/ч | 1,23 | 8.82 кВт/ч | 8,6223
Все затраты | | | | | 1264.69
Мой затраты | | | | | 573.9

### 3.1.2 Себестоимость лампы

Себестоимость моей лампы, представляет затраты на эл. Энергию (Расчёт эл. энергии - Таблица № 7) и на материалы (Расчёт материалов - Таблица № 6), которые представлены в таблице № 8. В таблице представлены используемые материалы, их стоимость, сколько потребовалось, сколько они в сумме стоят и во сколько они мне обошлись. В колонке стоимости материалов представлена их стоимость в сумме, там, где стоит прочерк обозначает, что мною не было затрачено, так как я усовершенствовал лампу и не потратился на заготовки, светодиодную ленту и некоторые эл. компоненты. В скобках указана их настоящая суммарная стоимость. В себе стоимости лампы учтены 2 печатные платы на сумму 0.8$(59.48) (1$ - 74.35), но минимальное количество плат заказа не может быть меньше 5 штук за плату (4$). Я заказал 2 платы по 5 штук, что должно было составить 8$, но при первом заказе у JLCPCB даётся скидка 2$, тем самым мои затраты на печатные платы составили 6$ (446.1 руб.).

Исходя из всех расчётов, себестоимость моей лампы составила 1264.69рубля, что на 76.22 рубля больше первой версии. Себестоимость рассчитывается из затратов на материалы, но я живу в отдалённом населённом пункте, где проблематично с эл. компонентами, светодиодными лентами и другими специфическими материалами в отличии от больших населённых пунктах. Поэтому некоторые материалы пришлось заказывать, и таким образом к моим тратам прибавиться плата за доставку. В моём случае пришлось заплатить за доставку печатных плат 6$ (446.1 руб.), а доставка эл. компонентов была бесплатной.

Но, поскольку основные материалы были взяты с первой версии лампы, для первого заказа печатных плат была скидка, а также я платил за доставку, мои затраты отличаются от себестоимости лампы. Мои затраты составляют из сэкономленных затрат на материалы и доставке = 573.9+ 446.1 = 1020 рублей.

Рекомендации по уменьшению затрат

4$ печатные платы

Выжидание скидок

Использование менее и дешёвых компонентов

## 3.2 Экологическое обоснование

Материалом конструкции является лиственница. Древесина - это экологически чистый материал, т.к. это природный материал который воспроизводится и разлагается в окружающей среде, получающийся только при механической обработке. Если соблюдать меры предосторожности, древесная пыль, отходы будут безопасны. Светодиодная лента имеет 90-98% КПД, это означает, что лишняя Эл.энергия не будет уходить в тепло, не вызовет пожара, а так же съэкономит на электроэнергии.

Поскольку не существует 100% КПД, рабочая лампа будет рассеивать 2-10% энергии в тепло. Нагрев древесины до 110° безопасен и вполне допустим в процессе сушки или обработки ее. При этой температуре происходит высушивание древесины и частичное выделение летучих веществ. На фото.1 и 2 изображены замеры температуры в нескольких участков лампы. На фото.3 изображён замер температуры LED-ленты. Замеры были произведены мной с помощью пирометра (тепловизора) FLIRtg165.

Замер температуры разных участков лампы с пирометра


Фото.1 Фото.2 Фото.3

Влияние на здоровье человека, а конкретнее на глаза будет зависить от двух факторов. Первый – от того какой блок питания мы будем использовать. В моём случае это импульсный блок питания от компьютера имеющий 30-40гГц которая безопасна для глаз т.к все частоты свыше 300Гц не воспринимаются мозгом и глазами. Второй фактор – яркость света, которой можно управлять через смартфон. Например, просыпаясь утром, лампу нужно включить 30-50% яркости, т.к только что, проснувшийсь, ваши глаза не привыкли к свету, а уже через некоторое время можно включить поярче (по умолчанию в программном коде лампы выставлена яркость 50%). Можно сделать вывод, что безопасность для глаз будет зависить от правильного использования лампы. Так же лампа будет безопасна для человека тем что в ней не может произойти замыкания, перенагрузки или перенапрежения. Для защиты от таких факторов в схеме 1 предусмотрен Dc-Dc преобразователь, канденсаторы и стабилизаторы напряжения. Все компонеты использованые в лампе не являются токсичными или радиоактивными, значит лампа безопасна для окружающей среды.

Врезультате моего иследования можно сделать следущий вывод: моя лампа экологически безопасна.

## 3.3 Маркетинговое обоснование

Как я уже рассматривал у общества большой интерес к интернету вещей, и как говорилось в пункте 1.1, IoT – занимает 6% мирового ВВП! Так же на диаграмме 1 был показан резкий скачок интереса общества к интернету вещей. И исходя из диаграммы концепция очень выгодна. Моя лампа – это одно из устройств из концепции Интернета вещей. И если верить источникам, то моя лампа будет хорошо продаваться.

Свой продукт я продвигаю следующим образом.

- Oбновляемая страница проекта на github. На странице все материалы, черчежы прогграммный код, источники, а так же стараница хорошо задокументирована. Github – этo платформа для разработчиков, даже можно сказать соц. Сеть разработчиков, и станица на этой платформе просматриваема.
- QR-code. За последние несколько лет всё активней стали использоваться QR-codes, ведь это удобно и бысро перейти к электронному источнику, и при продвижении продукта, это уктуально, ведь его можно бысто отсканировать и потребитель вероятнее всего выберет мой продукт.
- Статья на cxem.net. Для продвижения продукта, была написана статья на распространённый и посещаемый сайт cxem.net. Так же ресурс предлагоет денежное вознаграждение за предложенные статьи, а так же на данный момент на сайте идёт конкурс на тему «строим свой безопасный умный дом», где за лучшую статью дают призы.

Мы живём в 21 веке, когда нет ничего не возможного. И при имениии черчежей, схем и 3D моделей, лампу можно легко пустить в серию. Например сервис PCBWay предоставляет услуги узготовления печатных плат, запайки на них электронных компонентов, и изготовление любых деталий из большого выбора мматериалов, как из пластика, древесины и металла. Остаёться только сборка, прошивка и упаковка изделия. Но мои цели не комерчиские, и не направлены на получение прибыли. В моих интересах продвижение iot-систем среди интузиастов в виде своих проектов.

В результате моего анализа можно зделать вывод: что лампа будет хорошо продаваться.

## 3.4 Оценка выполненной работы

В этом проекте я поставил цель улучшить рабочую лампу до умной лампы V2. В пункте 1.2 разработка умной лампы я поставил функциональность моей лампы, где указал, что лампа должна быть выполнена качественней и декоративней, а также разработать печатную плату и улучшенное ПО, которое добавит большой ряд новых и умных функций. Но прежде чем рассказать о улучшениях, хочу напомнить о изначальных характеристиках:

- Мощность освещения 24 Вт.
- Максимальное потребление устройства 38 Вт.
- 5 функций динамической подсветки
- 7 цветовых режимов
- Управление только через интернет

И вот что добавилось и улучшилось:

- Появилось подробное описание и все файлы на Github
- Статья о устройстве на сайте cxem.net

ПО

- Исправление ошибок подключения к WiFi
- Исправление ошибки управления яркостью
- Оптимизация программного кода
- Добавления функции взаимодействия и обработка с устройствами подобного типа для дальнейшего их прорабатывания
- Добавления функции взаимодействия с внешними серверами (подключение к домашнему серверу (работа в локальной сети без участия интернета))
- Добавления функции выбора сети (сервера и wifi-сети)
- Добавление SSL протокола безопасности
- Добавление голосовое управление Яндекс Алиса
- Добавление функции обновления по воздуху (OTA)
- Добавление управления командами через терминал
- Добавление функции «зебра» (даёт возможность выбора цвета из 16 777 216 оттенков)
- Добавление функций новой радуги, RGB пропеллер и цветового режима ораньжевый

Электроника

- Разработана печатная плата заводского качества
- Добавление стабилизаторов напряжения
- Добавление своего DC-DC преобразователя
- Повышение качеств соединений
- Повышение качества и надёжности
- Повышен диапазон напряжения питания (10-18в), рекомендовано мной (12 – 15в)

Коструктив

- Добавление криволинейных линий
- Декоративная фрезеровка кромок
- Более качественное изготовление
- Чертежи, 3d модели и эскизы в эл. виде .png и .dwg

Моя лампа получилась очень удобной и современной с большим количеством функций. Приведу несколько примеров. Когда я паяю или выжигаю, я включаю полную яркость (24Вт). Когда я работаю за компьютером, я включаю лампу на 5 – 40% яркости для того чтобы не засвечивало экран. Когда я играю на компьютере, я включаю разноцветные режимы, для спокойных игр – динамическую подсветку, для динамических игр с повышенной внимательностью – мягкую и плавную подсветку. Когда я хочу уснуть, включаю голубой или бирюзовый, так как цвета с синим спектром успокаивают и помогают уснуть. Когда я ложусь спать с включённой лампой, я говорю Алисе, чтобы она выключила лампу через полчаса. Когда в гости приходит девушка, включаю пурпурный или вишнёвый. Когда хочу устроить тусовку, включаю такие режимы как: стробоскоп, RGB пропеллер, полицейскую мигалку или вращающиеся красный – синий. Все эти режимы отлично подходят для вечеринки или прослушивания музыки. Так же при уходе из дома, лампу можно дистанционно выключить или включить из любой точки мира, где есть интернет. Это актуально, когда вы уехали в отпуск, и можете иногда включать в комнате свет, для того чтобы гипотетический вор думал, что в доме кто-то есть.

Но для того чтобы пользоваться лампой надо скачать и настроить приложение и лампу. Инструкцию по настройки я опубликовал на github.

За время проекта я узнал: о концепции, истории и будущем интернета вещей, о стиле «прованс» и о множество сервисов. За время улучшения лампы я научился: основам проектирования печатных плат и принципиальных схем на сервисе EasyEDA [5], основам работы с git, оформлению репозиториев на github, научился основам создания чертежей в программе AutoCAD [8], ф так же научился разрабатывать свои электронные устройства. За время написания проекта, я закрепил и улучшил свои навыки: в обработке древесины, в оформлении описательной части проекта, в написании программного кода, а также обосновании экономического и экологического этапов.

Вывод: в ходе своего проекта я не только добился своей поставленной цели, но и много узнал, закрепил, улучшил и научился. Я считаю, что я справился с работой и проект закончен, но последущий год, материалы на github будут обновляться.

Окончательный вид изделия:

красивая_лампа

3.5 Реклама

Надоело вечно вставать с кровати и включать/выключать свет?

Хочешь иметь возможность в любой момент устроить светомузыку/вечеринку?

Хочешь улучшить своё качество жизни?

Тогда тебе срочно нужна наша лампа!

Сканируй Qr-code для получения подробной информации предложения!

QR-code.1

# 4 Список используемых источноков

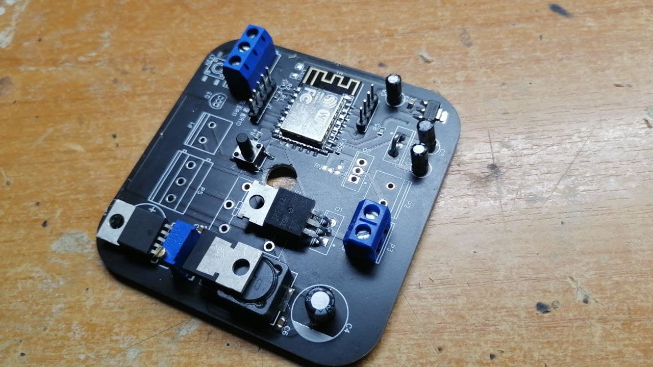
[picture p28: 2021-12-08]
images/electronic/зачистка.jpg

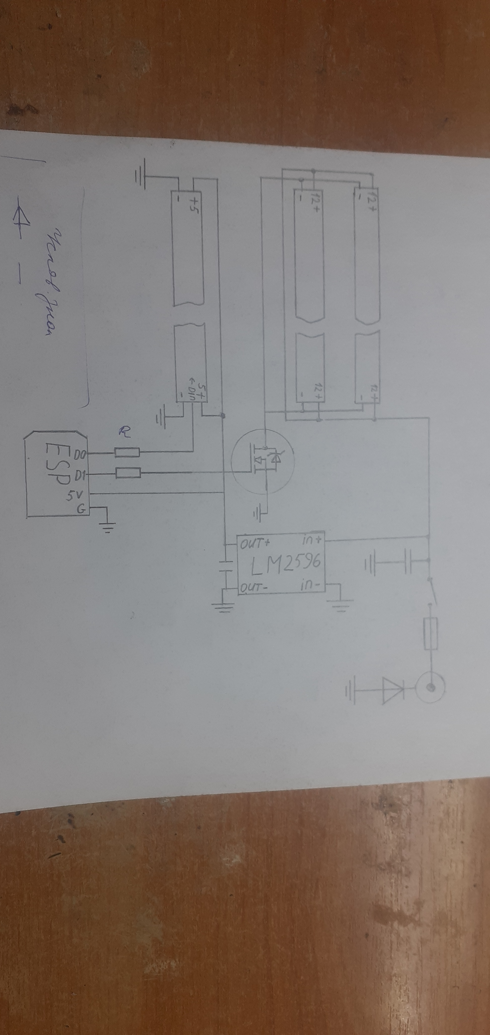
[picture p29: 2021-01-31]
images/electronic/12.ФОТО схемы подключения.jpg

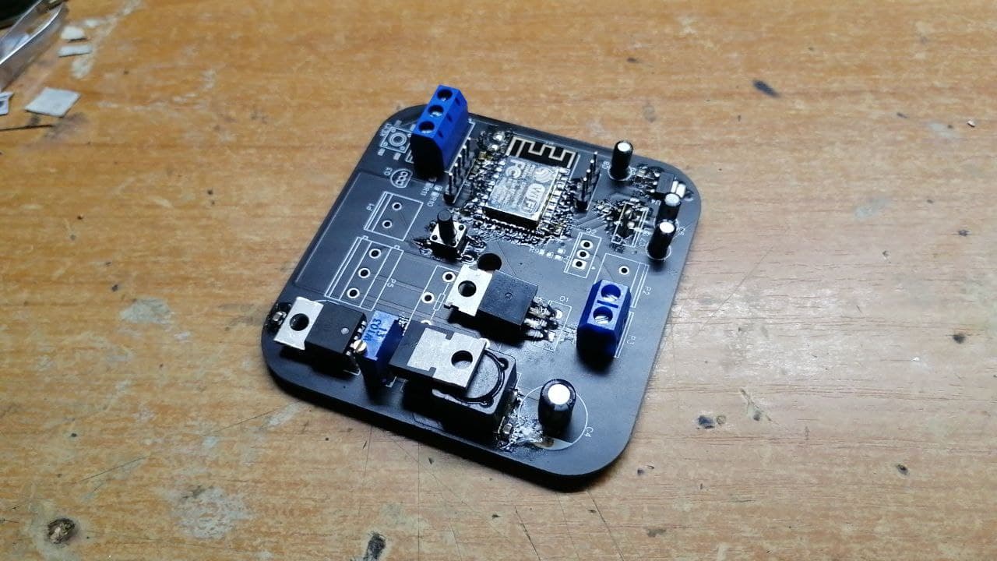
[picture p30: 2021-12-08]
images/electronic/спайка.jpg

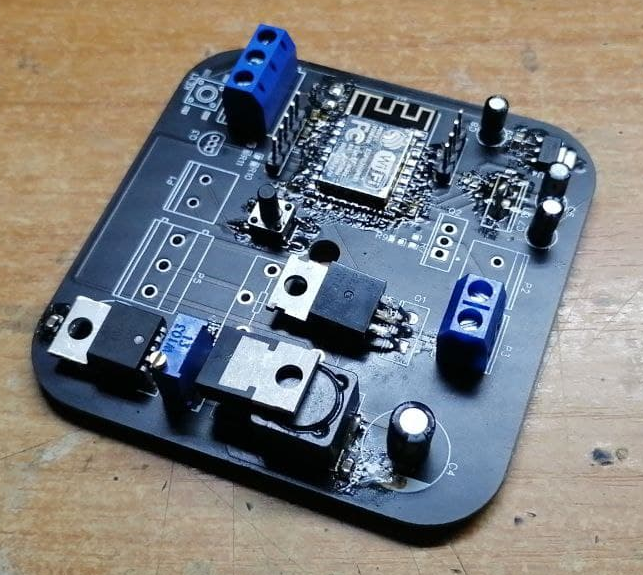
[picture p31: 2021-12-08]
images/electronic/спайка.png

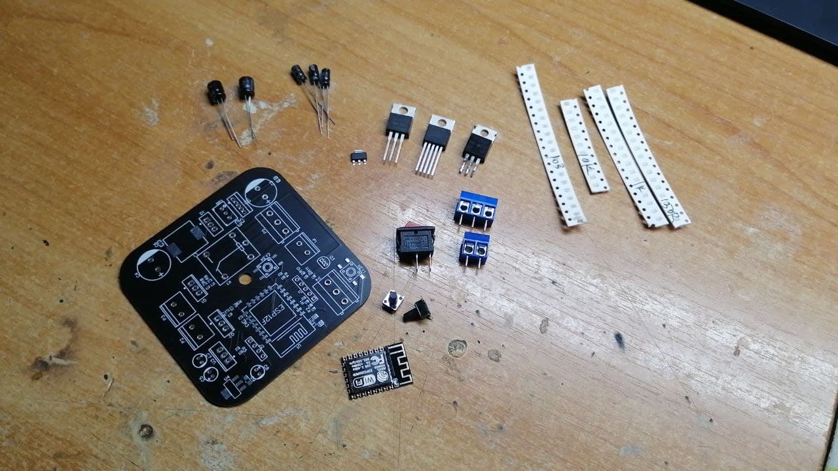
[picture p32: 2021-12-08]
images/electronic/подбор.jpg

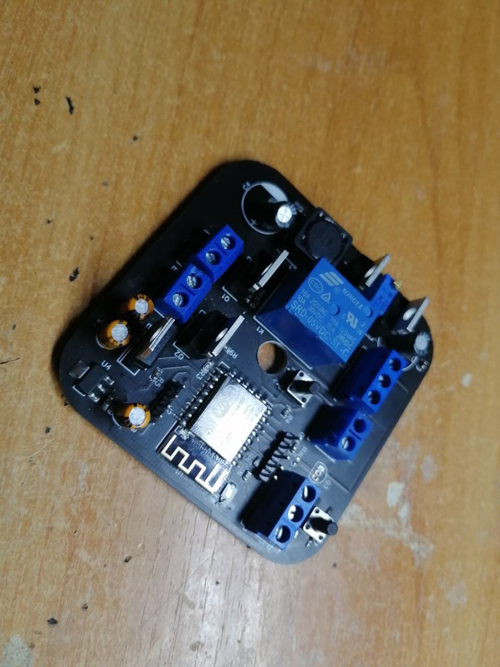
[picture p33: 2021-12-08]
images/electronic/устройство.jpg

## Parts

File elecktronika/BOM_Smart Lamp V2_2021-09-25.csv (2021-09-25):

ID | Name | Designator | Footprint | Quantity | Manufacturer Part | Manufacturer | Supplier | Supplier Part | Price | Pins | JLCPCB Part Class | Contributor | image
1 | 200uF | C1,C4 | CAP-TH_BD12.5-P5.00-D0.6-FD | 2 | LKML1602A221MF | Ymin | LCSC | C443147 | 0.247 | 2 | Extended Part | LCSC
2 | 100pF | C2,C3,C6 | C0603 | 3 | CC0603JRNPO9BN101 | YAGEO | LCSC | C14665 | 0.003 | 2 | Extended Part
3 | 22uF | C5,C7,C8 | CAP-TH_BD5.0-P2.00-D0.8-FD | 3 | 22uF 50V 5*11 | ValuePro | LCSC | C43346 | 0.012 | 2 | Extended Part
4 | 10uF | C9 | CASE-A_3216 | 1 |  |  |  |  |  | 2 |  | hjk413
5 | MBR1545CTG | D1 | TO-220-3_L10.0-W4.5-P2.54-T | 1 | MBR1545CTG | ON | LCSC | C2722 | 0.98 | 3 | Extended Part
6 | Выносные пины | J1 | HDR-M-2.54_1X5 | 1 |  |  | LCSC | C358687 | 0.024 | 5 |  | LCEDA_Lib
7 | Програматор | J2 | HDR-M-2.54_1X4 | 1 |  |  | LCSC | C124378 | 0.028 | 4 |  | LCEDA_Lib
8 | RelayHT3F-12VDC-SHG | K1 | RELAY-TH_HT3F-DCXX-X-X | 1 | RelayHT3F-12VDC-SHG | HTV | LCSC | C22022 | 0.41 | 5 | Extended Part
9 | K4-6×6_SMD | KEY1,KEY2 | KEY-SMD_4P-L6.0-W6.0-P3.90-LS10.0 | 2 | K2-6639SP-D4SC-04 | 韩国韩荣 | LCSC | C191626 | 0.046 | 4 |  | LCEDA_Lib
10 | 47uH | L1 | IND-SMD_L12.5-W12.5_SWRH1207B | 1 | SWRH1207B-470MT | Sunlord | LCSC | C60659 | 0.248 | 2 | Extended Part
11 | KT-1206Red LED | LED1 | LED1206-R-RD | 1 | KT-1206Red LED | KENTO | LCSC | C49018 |  | 2 | Extended Part
12 | Питание 10-16 В | P1 | CONN-TH_2P-P5.00 | 1 |  |  | LCSC |  |  | 2 |  | LCEDA_Lib
13 | Масфет | P2 | CONN-TH_2P-P5.00 | 1 |  |  | LCSC |  |  | 2 |  | LCEDA_Lib
14 | Лента 12В | P3 | CONN-TH_2P-P5.00 | 1 |  |  | LCSC |  |  | 2 |  | LCEDA_Lib
15 | Адресная лента | P4 | CONN-TH_3P-P5.00 | 1 |  |  | LCSC |  |  | 3 |  | LCEDA_Lib
16 | Реле | P5 | CONN-TH_3P-P5.00 | 1 |  |  | LCSC |  |  | 3 |  | LCEDA_Lib
17 | IRF530N | Q1,Q2 | TO-220AB-3_L10.4-W4.6-P2.54-L | 2 | IRF530N | VBsemi Elec | LCSC | C693220 | 0.81 | 3 | Extended Part | LCSC
18 | BC337 | Q3 | TO-92-3_L4.9-W3.7-P1.27-L | 1 | BC337 | CJ | LCSC | C154963 | 0.028 | 3 | Extended Part | LCSC
19 | 1k | R1 | R0603 | 1 |  |  |  |  |  | 2 |  | LCEDA_Lib
20 | 10k | R2,R3,R4,R5,R8,R9,R11 | R0603 | 7 |  |  |  |  |  | 2 |  | LCEDA_Lib
21 | 220 | R6,R7,R10 | R0603 | 3 |  |  |  |  |  | 2 |  | LCEDA_Lib
22 | R_3296W_EU | RP1 | RES-ADJ-TH_3296W | 1 |  |  | LCSC |  |  | 3 |  | LCEDA_Lib
23 | ESP12F | U1 | ESP-12F (ESP8266 MODULE) (BAGUNDA) | 1 | ESP-12F(ESP8266MOD) | Ai-Thinker | LCSC | C82891 | 1.475 | 22 |  | sandiko
24 | XL4016E1 | U2 | TO-220-5L_L10.2-W4.5-P1.71-L | 1 | XL4016E1 | XLSEMI | LCSC | C55881 | 1.254 | 5 | Extended Part
25 | 7812(TO-220) | U3 | TO-220-3_L10.0-W4.5-P2.54-L | 1 | MC7812BTG | ON | LCSC | C45387 | 0.561 | 3 |  | LCEDA_Lib | //image.lceda.cn/szlcsc/C45387.jpg
26 | AMS1117-3.3_C165482 | U4 | SOT-223_L6.5-W3.5-P2.30-LS7.0-BR | 1 | AMS1117-3.3 | SK | LCSC | C165482 | 0.054 | 4 | Extended Part | LCSC

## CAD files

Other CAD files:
dimensional_drawing/basis/3D_основание.dwg
dimensional_drawing/gusset/3D_косынка.dwg
dimensional_drawing/junction_box/распредкоробка_основа.dwg
dimensional_drawing/lamp/3D_лампа.dwg
dimensional_drawing/support/3D_опора.dwg
dimensional_drawing/basis/Чертеж_основания.dwg
dimensional_drawing/gusset/косынка_чертёж_черновик.dwg
dimensional_drawing/junction_box/распредкоробка_крышка.dwg
dimensional_drawing/support/Чертеж_опоры.dwg
dimensional_drawing/gusset/Чертеж_косынки.dwg

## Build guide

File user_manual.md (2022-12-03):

# Руководство по эксплуатации 
1. Скачать приложение [Blynk](https://play.google.com/store/apps/details?id=cc.blynk)

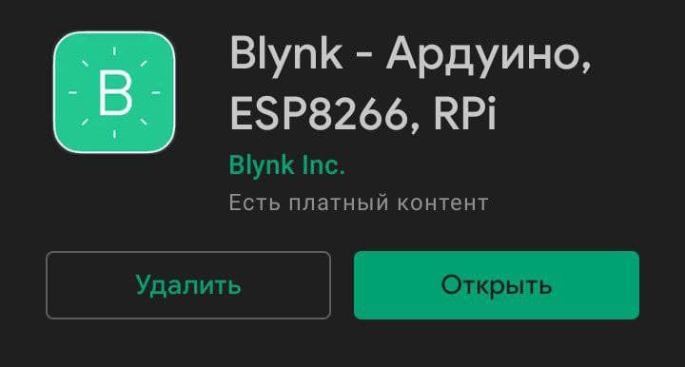
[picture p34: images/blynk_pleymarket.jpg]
blynk_pleymarket


1. Зарегистрироваться/войти на сервер (blync-cloud.com или свой локальный)

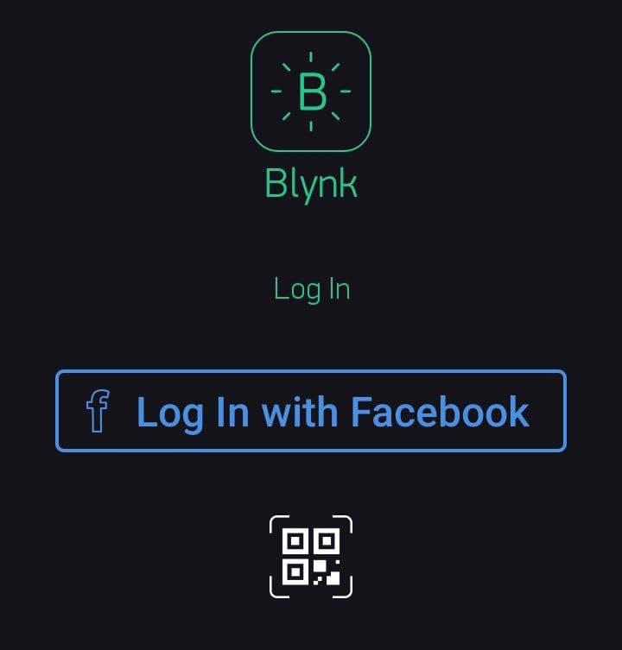
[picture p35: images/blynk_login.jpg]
blynk_login


1. Создать устройство esp и тип подключения WIfi

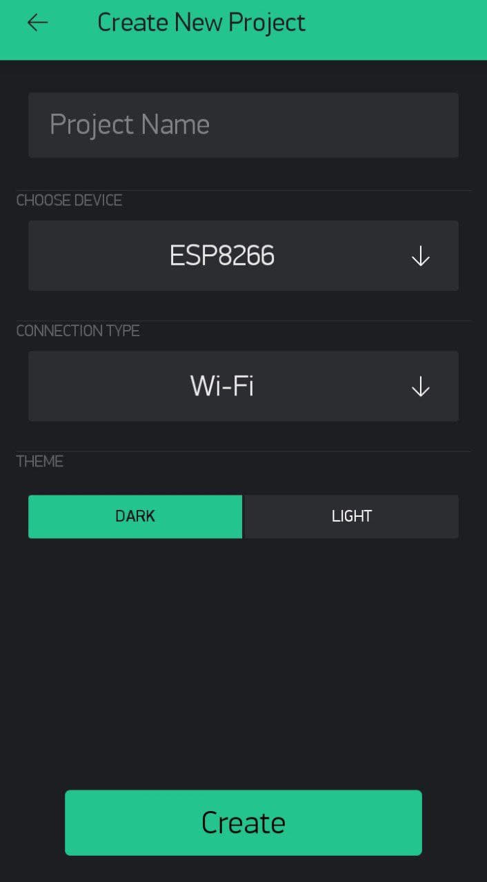
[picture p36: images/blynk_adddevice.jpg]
blynk_adddevice


1. Получить токен устройства на почту указуную при регистрации

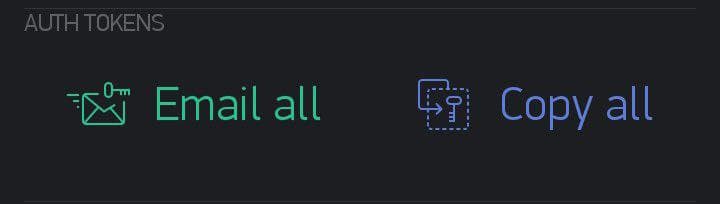
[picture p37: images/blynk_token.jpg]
токен


1. Скачать и установить [arduino IDE](https://www.arduino.cc/en/software), [гайд](https://alexgyver.ru/arduino-first/) ![]()

2. Скачать репозиторий с прошивкой с [github](https://github.com/Roman-Ivanitch/Project.9.class)

Qr-code

1. Открыть файл, и указать имя и пароль Wifi и токен который получили на почту

```C++
char ssid_home[] = "wi-fi-home-0000575";  // сеть wi-fi
char pass_home[] = "7851xdwifi";          // Пароль WiFi

char ssid_phone[] = "A30";                // Мобильная точка доступа WiFi
char pass_phone[] = "87651234";           // Пароль WiFi

```

```C++
char auth[] = "токен";          // лампа Blynk-cloud.com // Токен приложения Blynk
char auth_server[] = "токен";   // лампа local-server    // Токен приложения Blynk
```
Так же если используем свой сервер, то надо и задать его ip адрес, в моём случае, для доступа из сети интернет я подключил статический ip адрес (для оф.сервера задавать ip не нужно)
```C++
char ip_local[] = "ip адрес";             // свой server - local ip   // к примеру 192.168.88.200
char ip_net[] = "ip адрес";               // свой server - internet ip
```

8. Подключить плату к ПК чере TTL переходник(прагроматор) ![]()

9. Загружаем прошивку ![]()

10. В приложении настроить виджеты и виртуальные пины

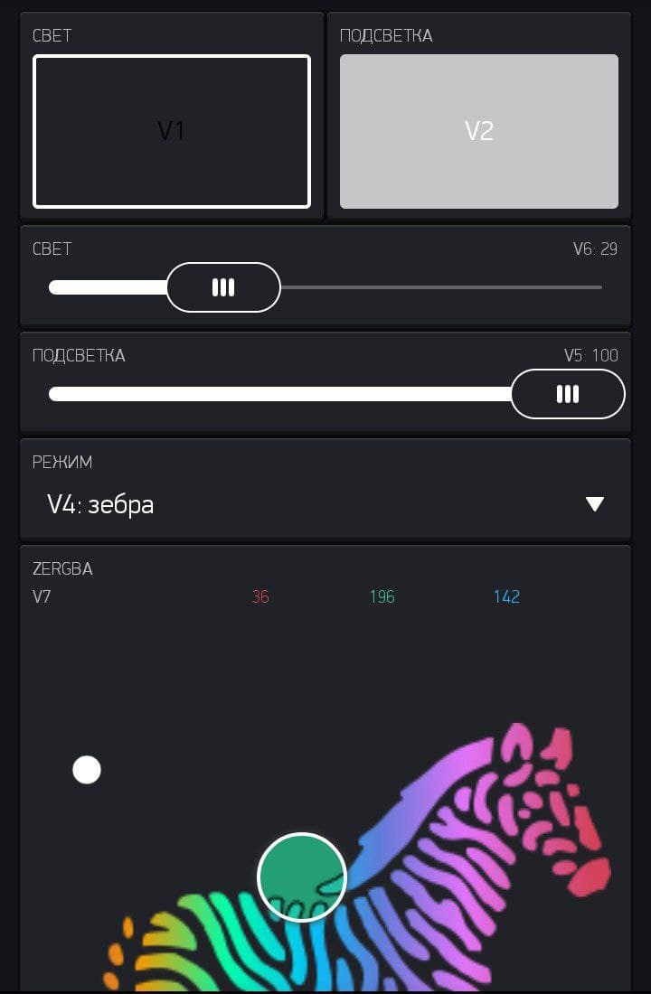
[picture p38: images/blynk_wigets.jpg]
blynk_wigets


1.  Тумблером на устройстве выбрать сеть wifi настроеные в прошивке ![]()

2.  Включить устьройство кнопкой взади

Готово!

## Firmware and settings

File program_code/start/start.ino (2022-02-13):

#include <BlynkSimpleEsp8266.h>  // Библиотека для работы с сервисом Blynk
#include <ESP8266WiFi.h>         // Библиотека для работы c ESP
#include <FastLED.h>             // Библиотека для работы с адресной лентой
#include <GyverPortal.h>
#include <EEPROM.h>
//------------------------------------НАСТРОЙКИ------------------------------------
#define LED_COUNT 52            // Число светодиодов в кольце/ленте

#define LED_DT 14               // Пин, куда подключен DIN ленты
#define LED 12                  // Пин подключения лампы

#define NET1 5                  // пин подключения кнопки выбора сети 1              network - сеть
#define NET2 13                 // пин подключения кнопки выбора сети 2

struct Data {
  char token[40];  // учетные данные, если запускаете впервый раз, 
  char ssid[20];   // то на web странице вводите токен из приложения Blynk, 
  char pass[20];   // название и пароль wi-fi/точки доступа, 
  char server[20]; // сервер Blynk (стандартный blynk-cloud.com) или же свой (ip сервера)
  uint16_t port;   // и порт ( обычно 8080, или 80, или если есть ssl, то 443 вроде...)

  char token1[40];
  char ssid1[20];
  char pass1[20];
  char server1[20];
  uint16_t port1;
};
Data data;
GyverPortal portal;

////////////////////////////////Служебные переменные////////////////////////////////
struct CRGB leds[LED_COUNT];

byte max_bright = 201;
byte red, green, blue;
int ihue = 0;
int idex = 0;

int TOP_INDEX = int(LED_COUNT / 2);
int EVENODD = LED_COUNT % 2;
int ledsX[LED_COUNT][3];
int BOTTOM_INDEX = 0;

int thissat   =  255;
int thisdelay =  20;
int thisstep  =  10;
int thishue   =  0;
int ibright   =  0;             //-BRIGHTNESS (0-255)

float tcount = 0.0;          //-INC VAR FOR SIN LOOPS

int brightnes;     // ярколсть подсветки (от 0 до 255)
int brightnes1;    // ярколсть лампы     
int lightnes;      // вкл/выкл подсветки 
int light;         // вкл/выкл лампы     
int  mode = 3;     // режим подсветки

void setup() {
  EEPROM.begin(500);     // читаем данные из памяти
  EEPROM.get(0, data);
  
  pinMode(LED, OUTPUT);                 // Пин лампы в режиме выхода
  pinMode(NET1, INPUT);                 // пин тумблера для настройки через web
  pinMode(NET2, INPUT);                 // пин тумблера выбоа сети2 
  
  LEDS.setBrightness(max_bright);                      // Ограничить максимальную яркость
  LEDS.addLeds<WS2811, LED_DT, GRB>(leds, LED_COUNT);  // Настрйоки для нашей ленты (ленты на WS2811, WS2812, WS2812B)
  one_color_all(0, 0, 0);                              // Погасить все светодиоды
  LEDS.show();                                         // Отослать команду
  
  if (digitalRead(NET1) == 1) web(); // положение тумблера для web интерфейса 
  else if (digitalRead(NET2) == 1)Blynk.begin(data.token1, data.ssid1, data.pass1, data.server1, data.port1); 
  else Blynk.begin(data.token, data.ssid, data.pass, data.server, data.port); // центральное положение тумблера
}

void loop() {
  Blynk.run();    // работа через интернет
  light_lamp();   // работа света
  mod ();         // работа режимов подсветки
}

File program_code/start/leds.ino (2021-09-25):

//-------------------------------one_color_all---------------------------------------
void one_color_all(int cred, int cgrn, int cblu) {   //-SET ALL LEDS TO ONE COLOR
  for (int i = 0 ; i < LED_COUNT; i++ ) {
    leds[i].setRGB( cred, cgrn, cblu);
  }
}
//-------------------------------one_color_allHSV---------------------------------------
void one_color_allHSV(int ahue) {                   //-SET ALL LEDS TO ONE COLOR (HSV)
  for (int i = 0 ; i < LED_COUNT; i++ ) {
    leds[i] = CHSV(ahue, thissat, 255);
  }
}
//-------------------------------rainbow_fade---------------------------------------
void rainbow_fade() {                      
  ihue++;
  if (ihue > 255) {
    ihue = 0;
  }
  for (int idex = 0 ; idex < LED_COUNT; idex++ ) {
    leds[idex] = CHSV(ihue, thissat, brightnes);
  }
  LEDS.show();
  delay(thisdelay);
}
//-------------------------------rainbow_loop---------------------------------------
void rainbow_loop() {                 
  idex++;
  ihue = ihue + thisstep;
  if (idex >= LED_COUNT) {
    idex = 0;
  }
  if (ihue > 255) {
    ihue = 0;
  }
  leds[idex] = CHSV(ihue, thissat, brightnes);
  LEDS.show();
  delay(thisdelay);
}
//-------------------------------flame---------------------------------------
void flame() {                                  
  int idelay = random(0, 35);
  float hmin = 0.1; float hmax = 45.0;
  float hdif = hmax - hmin;
  int randtemp = random(0, 3);
  float hinc = (hdif / float(TOP_INDEX)) + randtemp;
  int ihue = hmin;
  for (int i = 0; i <= TOP_INDEX; i++ ) {
    ihue = ihue + hinc;
    leds[i] = CHSV(ihue, thissat, brightnes);
    int ih = horizontal_index(i);
    leds[ih] = CHSV(ihue, thissat, brightnes);
    leds[TOP_INDEX].r = brightnes; leds[TOP_INDEX].g = brightnes; leds[TOP_INDEX].b = brightnes;
    LEDS.show();
    delay(idelay);
  }
}
//-------------------------------пропеллер---------------------------------------
void rgb_propeller() {                           //-m27-RGB PROPELLER
  idex++;
  int ghue = (thishue + 80) % 255;
  int bhue = (thishue + 160) % 255;
  int N3  = int(LED_COUNT / 3);
  int N6  = int(LED_COUNT / 6);
  int N12 = int(LED_COUNT / 12);
  for (int i = 0; i < N3; i++ ) {
    int j0 = (idex + i + LED_COUNT - N12) % LED_COUNT;
    int j1 = (j0 + N3) % LED_COUNT;
    int j2 = (j1 + N3) % LED_COUNT;
    leds[j0] = CHSV(thishue, thissat, 255);
    leds[j1] = CHSV(ghue, thissat, 255);
    leds[j2] = CHSV(bhue, thissat, 255);
  }
  LEDS.show();
  delay(thisdelay);
}
//-------------------------------другая радуга---------------------------------------
void new_rainbow_loop() {                      //-m88-RAINBOW FADE FROM FAST_SPI2
  ihue -= 1;
  fill_rainbow( leds, LED_COUNT, ihue );
  LEDS.show();
  delay(thisdelay);
}
//-------------------------------ems_lightsALL---------------------------------------
void ems_lightsALL() {                  
  idex++;
  if (idex >= LED_COUNT) {
    idex = 0;
  }
  int idexR = idex;
  int idexB = antipodal_index(idexR);
  int thathue = (thishue + 160) % 255;
  leds[idexR] = CHSV(thishue, thissat, brightnes);
  leds[idexB] = CHSV(thathue, thissat, brightnes);
  LEDS.show();
  delay(thisdelay);
}
//-------------------------------Strobe---------------------------------------
void Strobe(byte red, byte green, byte blue, int StrobeCount, int FlashDelay, int EndPause) {
  for (int j = 0; j < StrobeCount; j++) {
    setAll(red, green, blue);
    FastLED.show();
    delay(FlashDelay);
    setAll(0, 0, 0);
    FastLED.show();
    delay(FlashDelay);
  }
  delay(EndPause);
}
//-------------------------------ems_lightsSTROBE---------------------------------------
void ems_lightsSTROBE() {                
  int thishue = 0;
  int thathue = (thishue + 160) % 255;
  for (int x = 0 ; x < 5; x++ ) {
    for (int i = 0 ; i < TOP_INDEX; i++ ) {
      leds[i] = CHSV(thishue, thissat, 255);
    }
    LEDS.show(); delay(thisdelay);
    one_color_all(0, 0, 0);
    LEDS.show(); delay(thisdelay);
  }
  for (int x = 0 ; x < 5; x++ ) {
    for (int i = TOP_INDEX ; i < LED_COUNT; i++ ) {
      leds[i] = CHSV(thathue, thissat, 255);
    }
    LEDS.show(); delay(thisdelay);
    one_color_all(0, 0, 0);
    LEDS.show(); delay(thisdelay);
  }
}

//-------------------------------патриотизм---------------------------------------

void rwb_march() {                    //-m15-R,W,B MARCH CCW
  copy_led_array();
  int iCCW;
  idex++;
  if (idex > 2) {
    idex = 0;
  }
  switch (idex) {
    case 0:
      leds[0].r = 255;
      leds[0].g = 0;
      leds[0].b = 0;
      break;
    case 1:
      leds[0].r = 255;
      leds[0].g = 255;
      leds[0].b = 255;
      break;
    case 2:
      leds[0].r = 0;
      leds[0].g = 0;
      leds[0].b = 255;
      break;
  }
  for (int i = 1; i < LED_COUNT; i++ ) {
    iCCW = adjacent_ccw(i);
    leds[i].r = ledsX[iCCW][0];
    leds[i].g = ledsX[iCCW][1];
    leds[i].b = ledsX[iCCW][2];
  }
  LEDS.show();
  delay(thisdelay);
}


//-------------------------------Радиация---------------------------------------
void radiation() {                   //-m16-SORT OF RADIATION SYMBOLISH-
  int N3  = int(LED_COUNT / 3);
  int N6  = int(LED_COUNT / 6);
  int N12 = int(LED_COUNT / 12);
  for (int i = 0; i < N6; i++ ) {    //-HACKY, I KNOW...
    tcount = tcount + .02;
    if (tcount > 3.14) {
      tcount = 0.0;
    }
    ibright = int(sin(tcount) * 255);
    int j0 = (i + LED_COUNT - N12) % LED_COUNT;
    int j1 = (j0 + N3) % LED_COUNT;
    int j2 = (j1 + N3) % LED_COUNT;
    leds[j0] = CHSV(thishue, thissat, ibright);
    leds[j1] = CHSV(thishue, thissat, ibright);
    leds[j2] = CHSV(thishue, thissat, ibright);
  }
  LEDS.show();
  delay(thisdelay);
}
//-------------------------------Функции---------------------------------------
void random_march() {                   //-m14-RANDOM MARCH CCW
  copy_led_array();
  int iCCW;
  leds[0] = CHSV(random(0, 255), 255, 255);
  for (int idex = 1; idex < LED_COUNT ; idex++ ) {
    iCCW = adjacent_ccw(idex);
    leds[idex].r = ledsX[iCCW][0];
    leds[idex].g = ledsX[iCCW][1];
    leds[idex].b = ledsX[iCCW][2];
  }
  LEDS.show();
  delay(thisdelay);
}
//-------------------------------Функции---------------------------------------
void setAll(byte red, byte green, byte blue) {
  for (int i = 0; i < LED_COUNT; i++ ) {
    setPixel(i, red, green, blue);
  }
  FastLED.show();
}
void setPixel(int Pixel, byte red, byte green, byte blue) {
  leds[Pixel].r = red;
  leds[Pixel].g = green;
  leds[Pixel].b = blue;
}

int antipodal_index(int i) {
  int iN = i + TOP_INDEX;
  if (i >= TOP_INDEX) {
    iN = ( i + TOP_INDEX ) % LED_COUNT;
  }
  return iN;
  }
  
  int horizontal_index(int i) {
  //-ONLY WORKS WITH INDEX < TOPINDEX
  if (i == BOTTOM_INDEX) {
    return BOTTOM_INDEX;
  }
  if (i == TOP_INDEX && EVENODD == 1) {
    return TOP_INDEX + 1;
  }
  if (i == TOP_INDEX && EVENODD == 0) {
    return TOP_INDEX;
  }
  return LED_COUNT - i;
}
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

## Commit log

2021-01-10 Add files via upload
    Добавление реферата проекта
2021-01-29 Переименовал некоторое
2021-01-31 Добавление папки изображений
2021-09-25 Create README.md
    Первоначальное описание, описание что есть(будет) но нет пока
2021-09-25 папка схемы,гербер файлы, список электронных компонентов
    [BOM_Smart Lamp V2_2021-09-25.csv]
2021-09-25 материалы
2021-09-25 летние наработки(раньше гитом пользоваться не умел:)) добавлена фенкция зебра, исправлена ошибка неправильного управления масфет ключом, структуирование кода
    [blynk.ino, function.ino, leds.ino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]
2021-09-25 Update start.ino
    безопасность типа
2021-09-25 Update start.ino
    бережёного бог бережёт
2021-09-25 Update readme.ino
    типо безопасность 2
    ( да я знаю что умный человек может посмотреть по комитам и предыдущим версиям, но лучше пока ничего не придумал)
2021-09-25 хорошее учебное пособие нашёл
2021-10-17 исходники
2021-10-17 по маленьку что бы не забыть
2021-10-19 переключатель серверовор
2021-10-27 Markdown расширение md
2021-10-29 исправил ошибки руского языка)
2021-10-30 Delete sssas
    хуня какаято
2021-10-30 Delete x
    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
2021-11-07 освободил лишнее место
    [GaverlampP.SLDASM, GaverlampTigVer_Base.STL, GaverlampTigVer_Cap.STL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]
2021-11-08 exampleЭ
2021-12-08 yes, update
    [Чертеж_косынки.dwg, Чертеж_опоры.dwg, Чертеж_основания.dwg]
2021-12-12 add 3D model end update drawings
    [3D_косынка.dwg, 3D_лампа.dwg, 3D_опора.dwg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]
2022-02-13 добавлен web интерфейс, теперь можно при положении тумблера в сторону кнопки включения, подключится к точке доступа лампы, в web интерфейсе настроить SSID, PASS, token Blynk, server, port. Так же чер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
